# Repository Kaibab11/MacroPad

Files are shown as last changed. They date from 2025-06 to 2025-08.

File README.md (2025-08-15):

# MacroPad

A customizable macro pad project featuring hardware design files, firmware, and a GUI for configuration.

## Features

- Custom PCB design files for a macro pad
- CircuitPython-based firmware for key handling and display
- Modular codebase for easy extension
- GUI software for configuration (see [Software/GUI](Software/GUI))
- Assembly and fabrication documentation

## Directory Structure

- **Firmware/**: CircuitPython firmware, including main logic (`main.py`), macro handling (`macroPad.py`), display support (`display/display.py`), and KMK keyboard modules.
- **PCB_FIles/**: Hardware design files, including schematic, PCB layout, and fabrication reports.
- **Software/GUI/**: GUI tools for configuring the macro pad.
- **Assembly/**, **Fabrication/**, **Schematic Prints/**: Documentation for building and assembling the macro pad.

## Getting Started

1. **Hardware**: Review PCB and schematic files in [PCB_FIles](PCB_FIles).
2. **Firmware**: Flash CircuitPython and copy files from [Firmware](Firmware) to your device.
3. **Configuration**: Use the GUI in [Software/GUI](Software/GUI) to set up macros.

## Requirements

- CircuitPython-compatible microcontroller
- KMK firmware (included in [Firmware/kmk](Firmware/kmk))
- Python 3.x for GUI tools

## License

This project is for personal and educational use.

---

For more details, see individual folders and documentation.

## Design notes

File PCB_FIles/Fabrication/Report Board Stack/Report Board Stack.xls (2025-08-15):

Board Stack Report
Stack Up |  | Layer Stack
Layer | Rigid | Name | Material | Thickness | Constant
1 |  | Top Overlay |  | 0mm
2 |  | Top Solder | Solder Resist | 0.0127mm | 3.3
3 |  | Top Layer |  | 0.01778mm
4 |  | Dielectric1 | FR-4 | 1.4986mm | 4.3
5 |  | Bottom Layer |  | 0.01778mm
6 |  | Bottom Solder | Solder Resist | 0.0127mm | 3.3
7 |  | Bottom Overlay |  | 0mm
 | Height : 1.55956mm

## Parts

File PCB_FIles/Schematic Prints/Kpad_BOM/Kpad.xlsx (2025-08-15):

Designator | Description | Name | Quantity | Manufacturer 1 | Manufacturer Part Number 1 | Supplier 1 | Supplier Part Number 1
MT1 | Incremental Encoder, 12 Mm, Contact Rating 10 Ma - 5 Vdc | PEC11R-4215F-S0024 | 1 | Bourns | PEC11R-4215F-S0024 | Arrow Electronics | PEC11R-4215F-S0024
R1, R2, R3 | Axial Resistor, 10 KOhm, +/- 1%, 0.25 W, -55 to 155 degC, 2-Pin THD, RoHS, Bulk | MFR-25FBF52-10K | 3 | Yageo | MFR-25FBF52-10K | Avnet | MFR-25FBF52-10K
SW1, SW2, SW3, SW4, SW5, SW6, SW7, SW8, SW9, SW10, SW11, SW12 | SPST momentary switch 15.40mmx15.40mm | KS-8A10B055NW | 12 | Gateron | KS-8A10B055NW-D194 | Divinikey | DK002607
U1, U3 | Parallel-Load Shift Register, 8-Bit, 2 to 6 V, -40 to 125 degC, 16-Pin PDIP (N), Pb-Free (RoHS), Rail/Tube | SN74HC165N | 2 | Texas Instruments | SN74HC165N | Digikey | 296-8251-5-ND
U2 | RP2040 XIAO RP2040 series ARMÂ® CortexÂ®-M0+ MCU 32-Bit Embedded Evaluation Board | 102010428 | 1 | Seeed Technology Co., Ltd | 102010428 | Digikey | 1597-102010428-ND
U4 | MakerFocus 2pcs I2C OLED Display Module 0.91 Inch | 8541549353 | 1 | Shenzhen Jin Ma Ding Electronics Co., Ltd. | QG-2832TLBFG02 | MakerFocus | 8541549353
U5, U6 | RES ARRAY 7 RES 1K OHM 14DIP | 4114R-1-102LF | 2 | Bourns | 4114R-1-102LF | Newark | 32K8310

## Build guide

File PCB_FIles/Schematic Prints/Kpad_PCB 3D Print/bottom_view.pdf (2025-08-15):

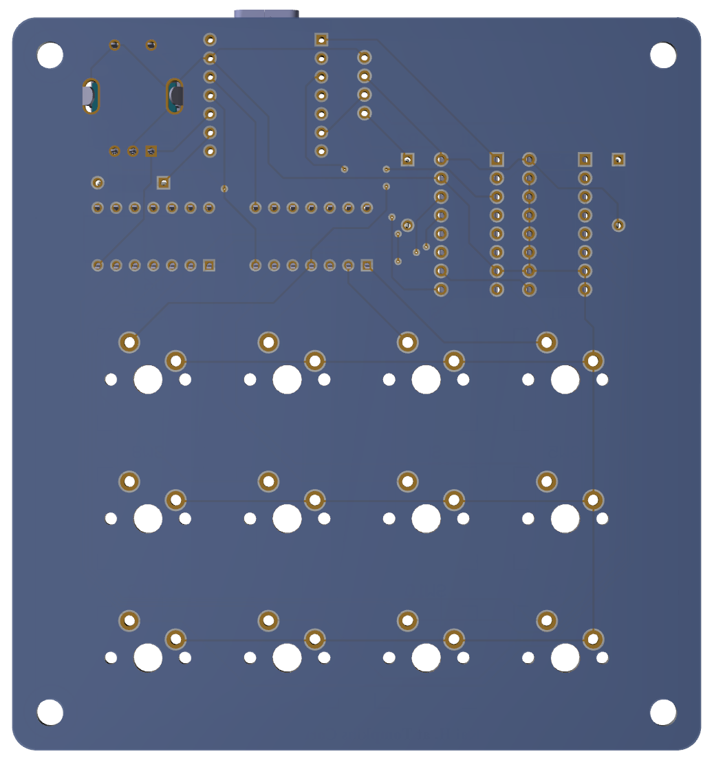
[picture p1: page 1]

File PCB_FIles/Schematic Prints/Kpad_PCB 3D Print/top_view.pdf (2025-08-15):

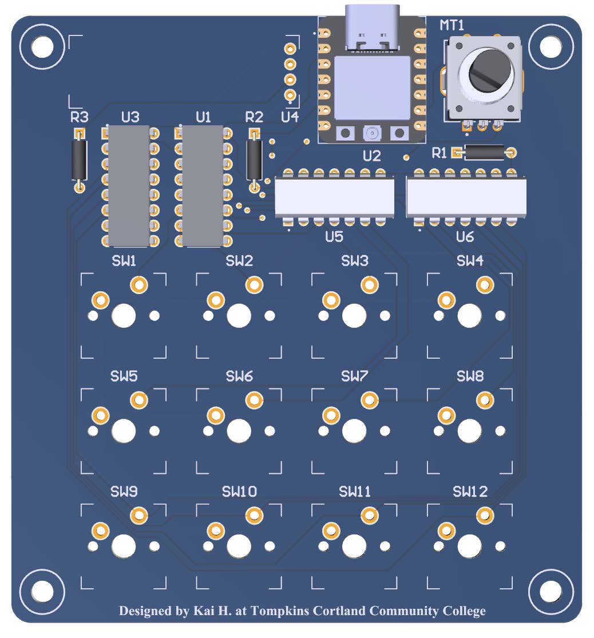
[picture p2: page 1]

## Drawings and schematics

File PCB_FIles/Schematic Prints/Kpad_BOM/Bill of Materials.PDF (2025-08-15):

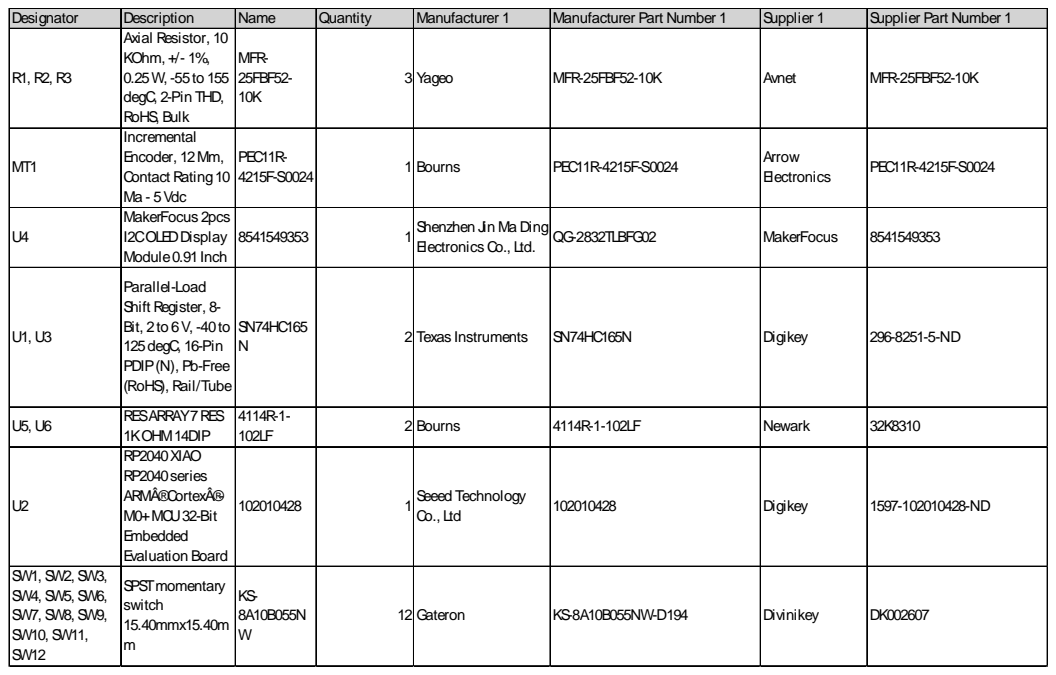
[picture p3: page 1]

Designator | Description | Name | Quantity | Manufacturer 1 | Manufacturer Part Number 1 | Supplier 1 | Supplier Part Number 1
R1, R2, R3 | Axial Resistor, 10 KOhm, +/- 1%, 0.25W, -55to 155 degC, 2-Pin THD, RoHS, Bulk | MFR-25FBF52-10K | 3 Yageo | | MFR-25FBF52-10K | Avnet | MFR-25FBF52-10K

MT1 | Incremental Encoder, 12Mm, Contact Rating10 Ma - 5Vdc | PEC11R-4215F-S0024 | 1 Bourns | | PEC11R-4215F-S0024 | Arrow Electronics | PEC11R-4215F-S0024

U4 | MakerFocus 2pcs I2COLEDDisplay Module0.91Inch | 8541549353 | 1 Shenzhen Jin Ma Ding | Electronics Co., Ltd. | QG-2832TLBFG02 | MakerFocus | 8541549353

U1, U3 | Parallel-Load Shift Register, 8-Bit, 2to 6V, -40to 125degC, 16-Pin PDIP(N), Pb-Free (RoHS), Rail/Tube | SN74HC165 N | 2 Texas Instruments | | SN74HC165N | Digikey | 296-8251-5-ND

U5, U6 | RESARRAY7RES 1KOHM14DIP | 4114R-1-102LF | 2 Bourns | | 4114R-1-102LF | Newark | 32K8310

U2 | RP2040XIAO RP2040series ARMÂ®CortexÂ®-M0+MCU32-Bit Embedded Evaluation Board | 102010428 | 1 Seeed Technology | Co., Ltd | 102010428 | Digikey | 1597-102010428-ND

SW1, SW2, SW3, SW4, SW5, SW6, SW7, SW8, SW9, SW10, SW11, SW12 | SPSTmomentary switch 15.40mmx15.40m m | KS-8A10B055N W | 12 Gateron | | KS-8A10B055NW-D194 | Divinikey | DK002607

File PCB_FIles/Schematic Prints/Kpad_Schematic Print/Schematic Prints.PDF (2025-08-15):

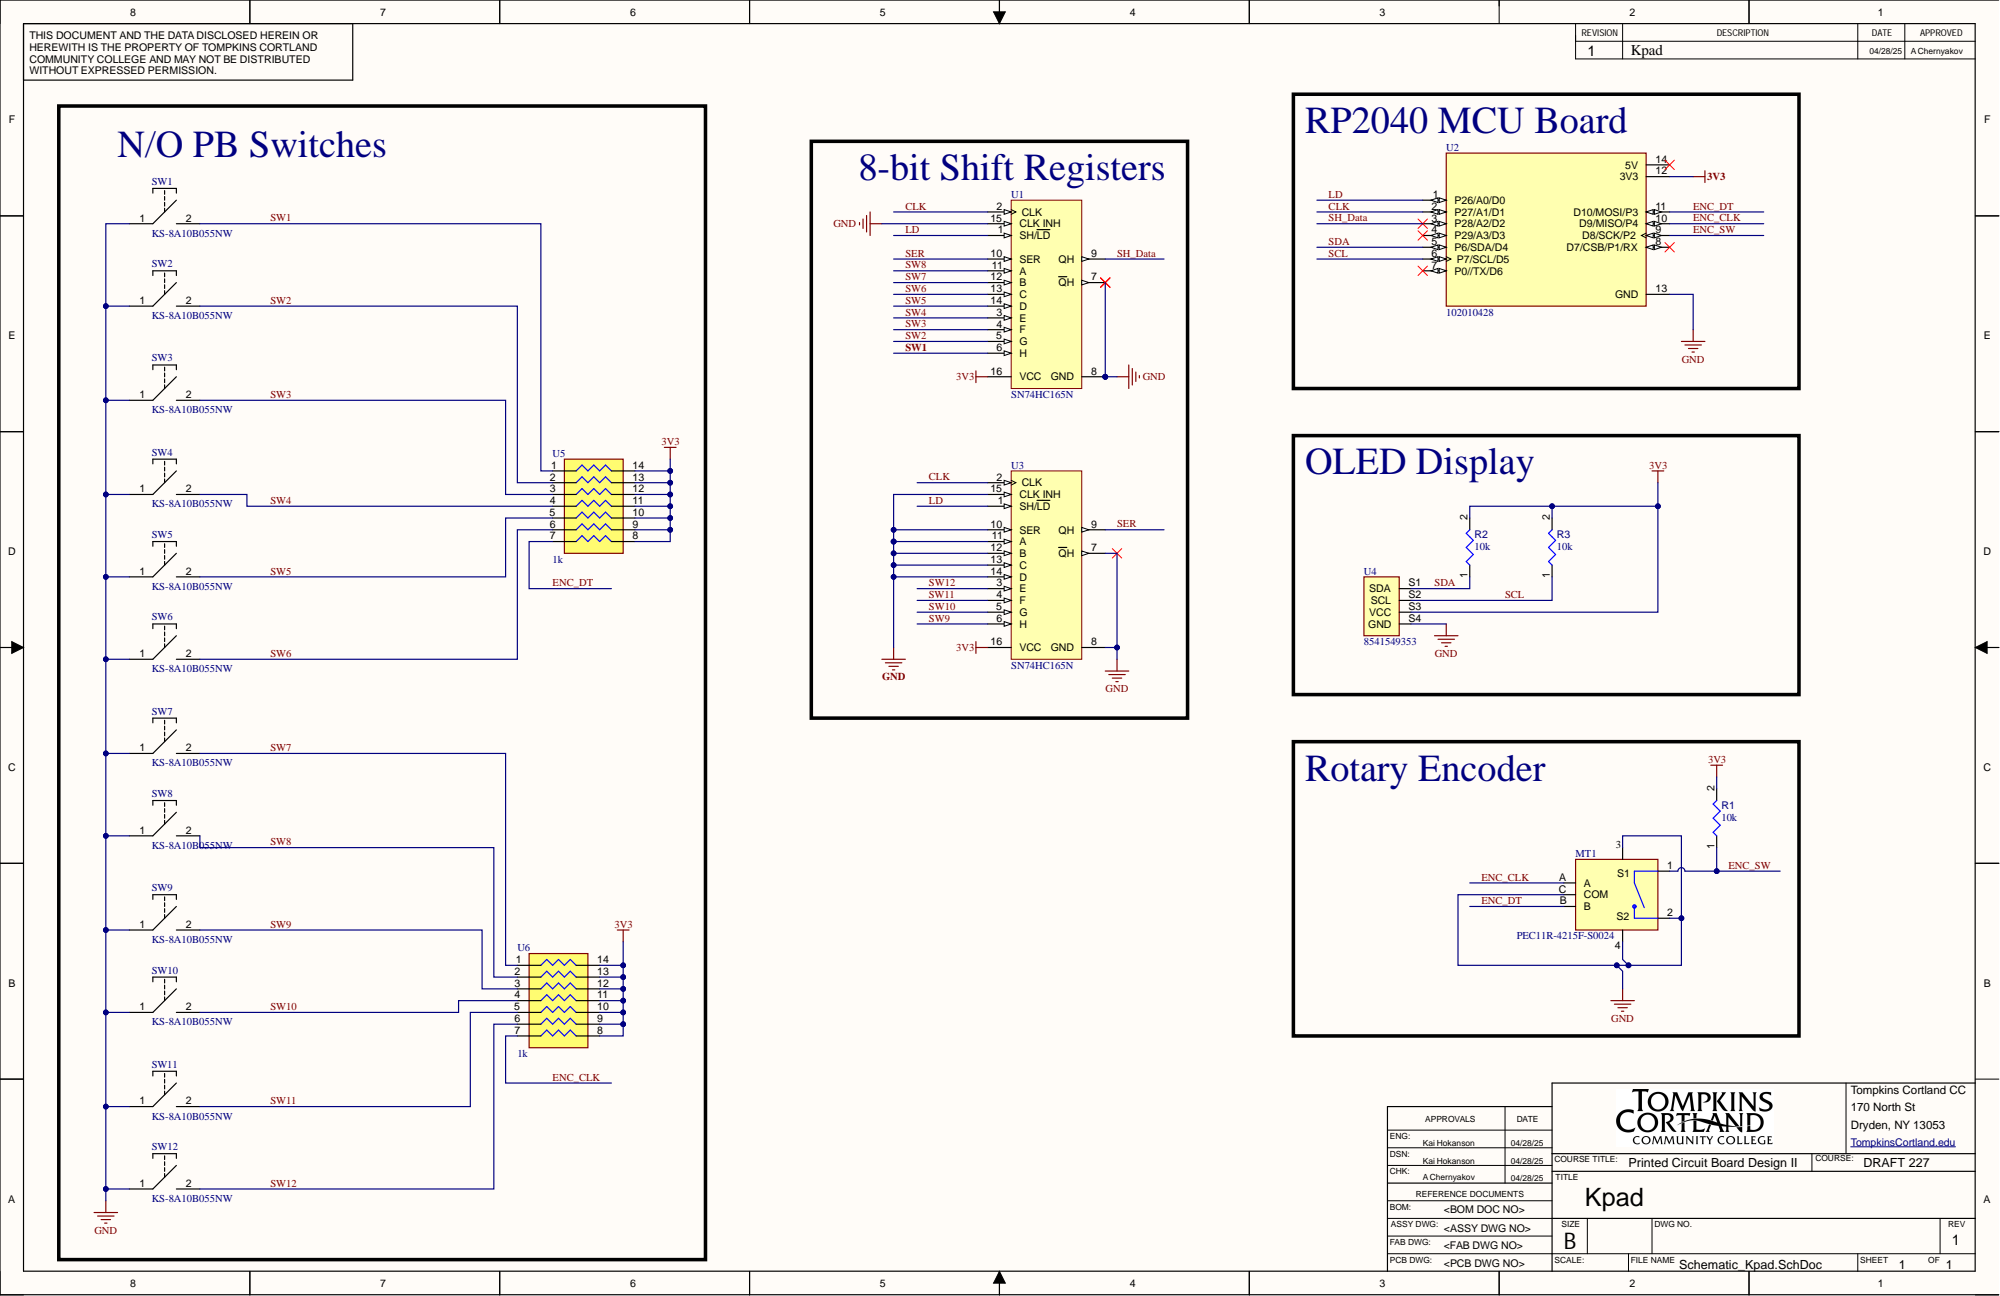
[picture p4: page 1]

HEREWITH IS THE PROPERTY OF
COMMUNITY COLLEGE AND MAY NOT BE DISTRIBUTED
WITHOUT EXPRESSED PERMISSION.
N/O PB Switches

Tompkins Cortland CC 170 North St TompkinsCortland. e d u

ENG : Kai Hokanson | 04/28/2 5

DSN: Kai Hokanson | 04/28/2 5

COURSE TITLE: Printed Circuit Board Design II | COURSE: DRAFT 227

CHK: A Chernyakov | 04/28/2 5

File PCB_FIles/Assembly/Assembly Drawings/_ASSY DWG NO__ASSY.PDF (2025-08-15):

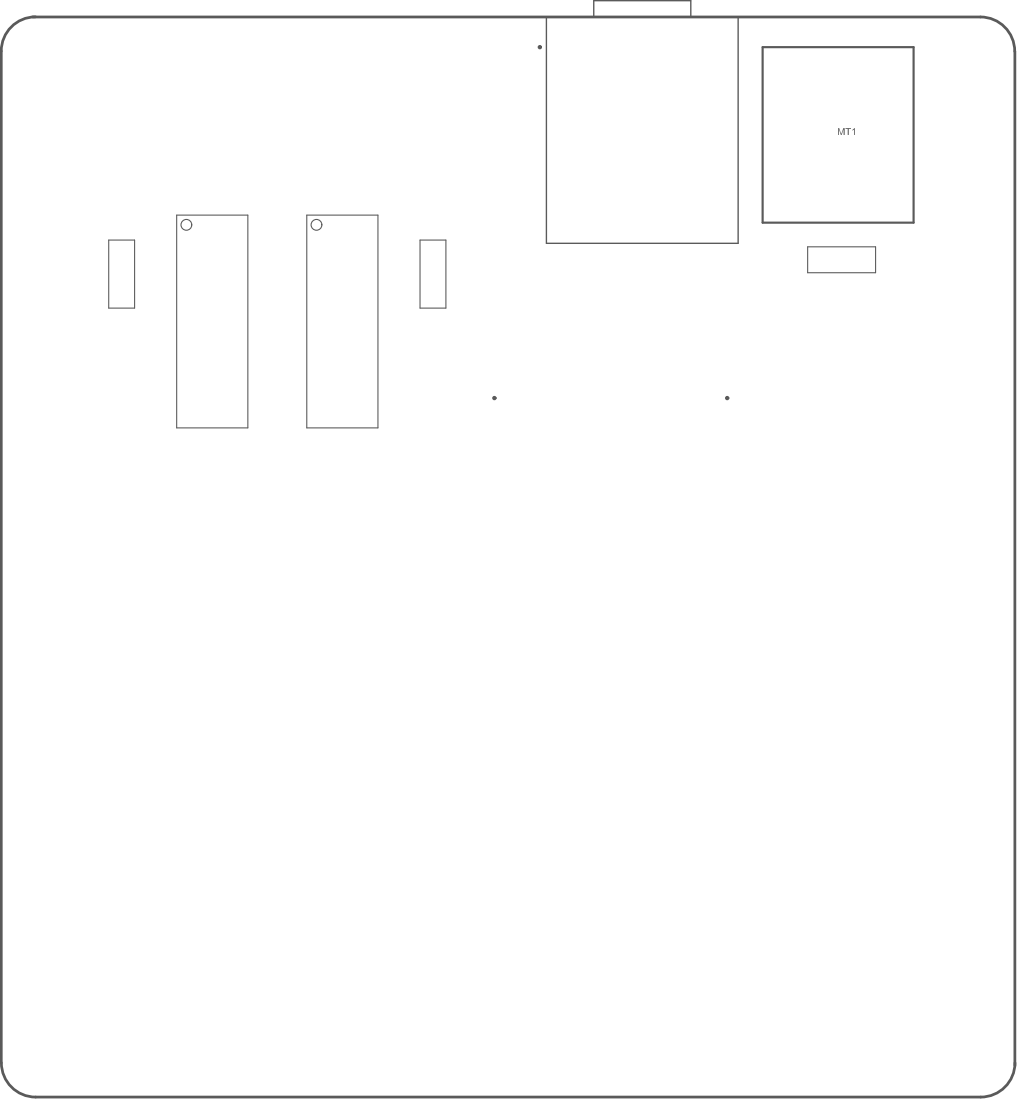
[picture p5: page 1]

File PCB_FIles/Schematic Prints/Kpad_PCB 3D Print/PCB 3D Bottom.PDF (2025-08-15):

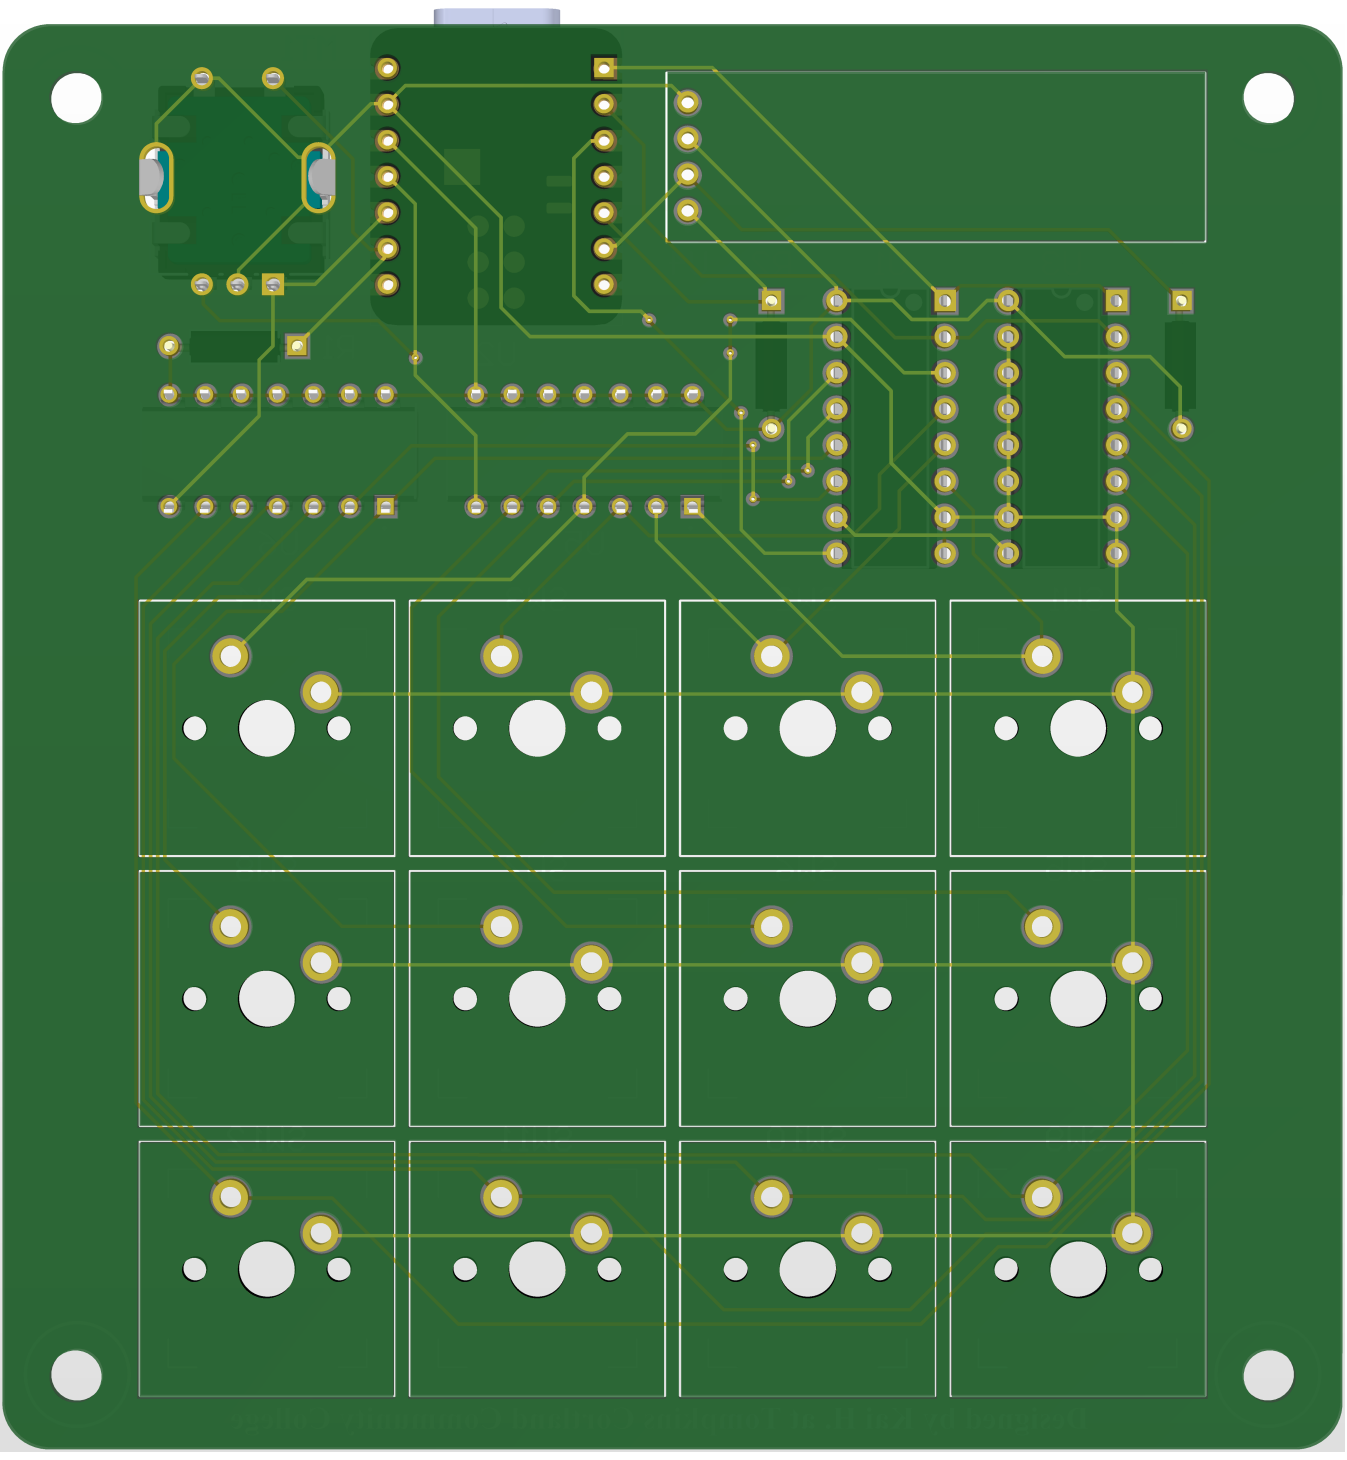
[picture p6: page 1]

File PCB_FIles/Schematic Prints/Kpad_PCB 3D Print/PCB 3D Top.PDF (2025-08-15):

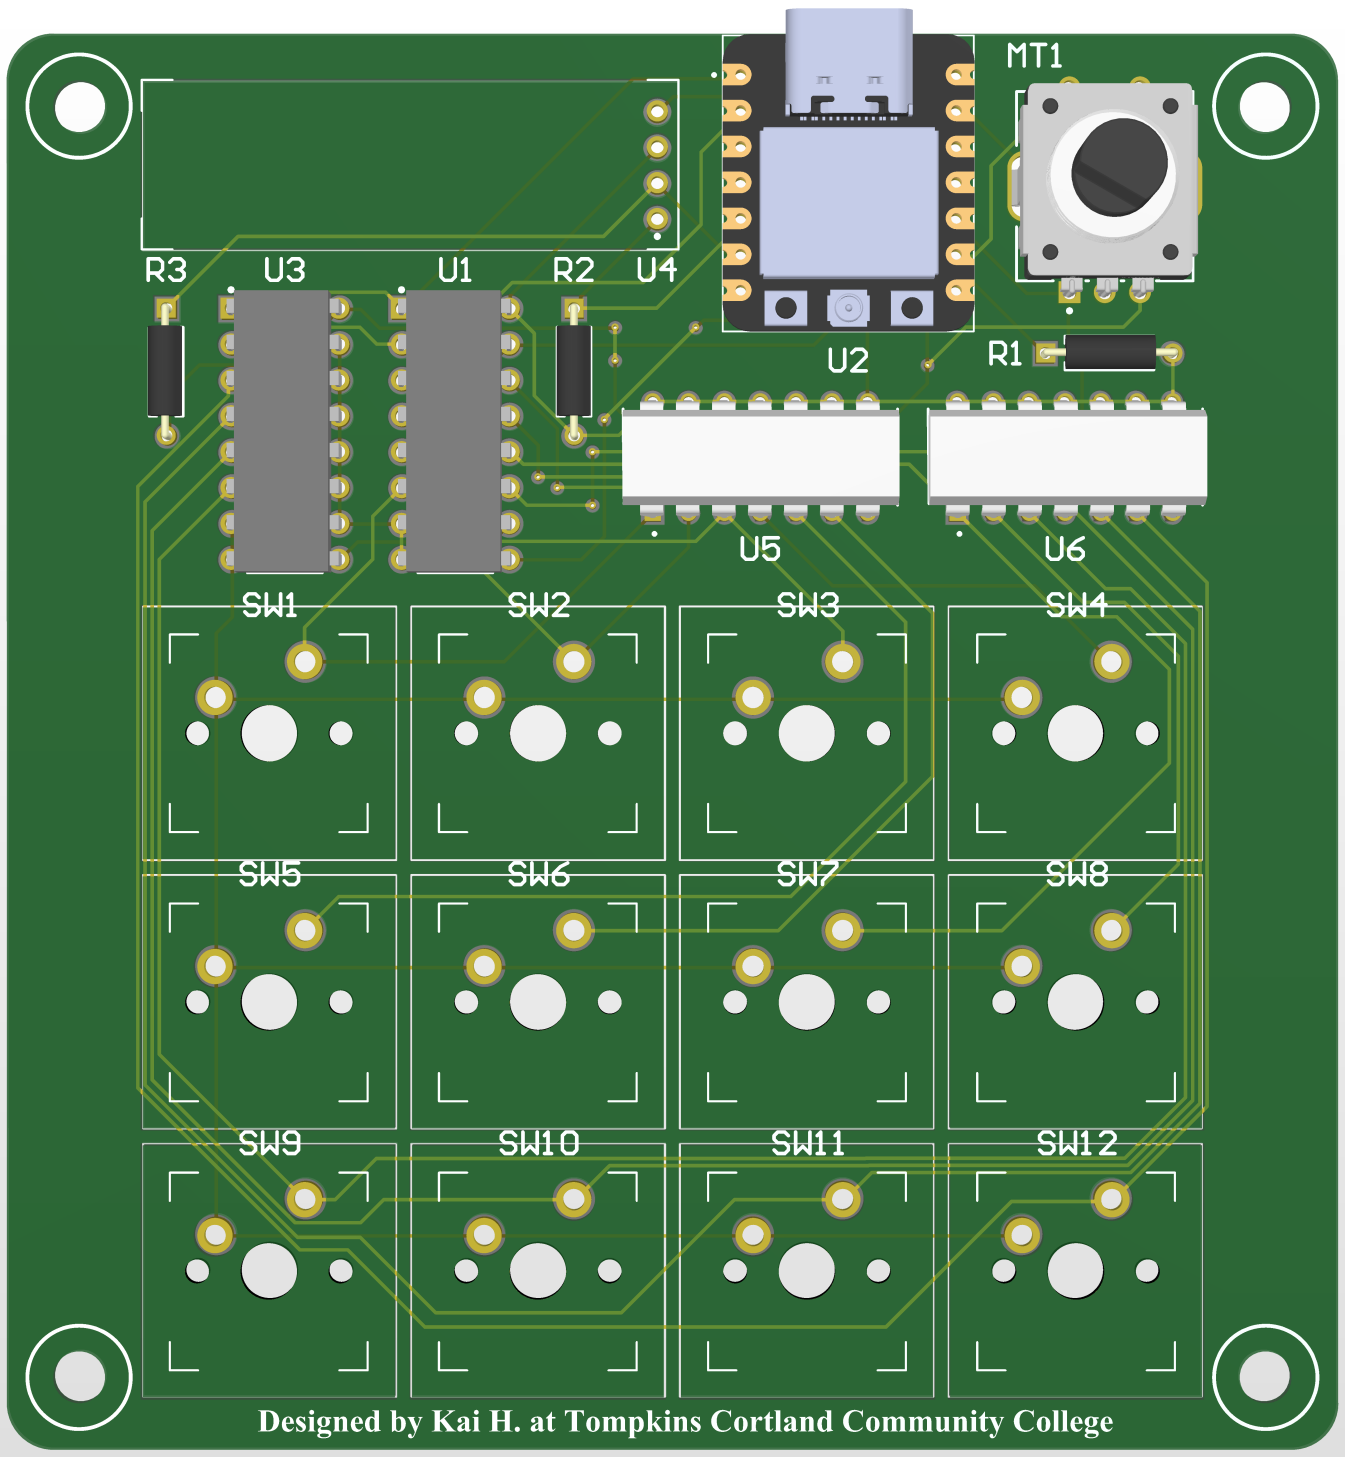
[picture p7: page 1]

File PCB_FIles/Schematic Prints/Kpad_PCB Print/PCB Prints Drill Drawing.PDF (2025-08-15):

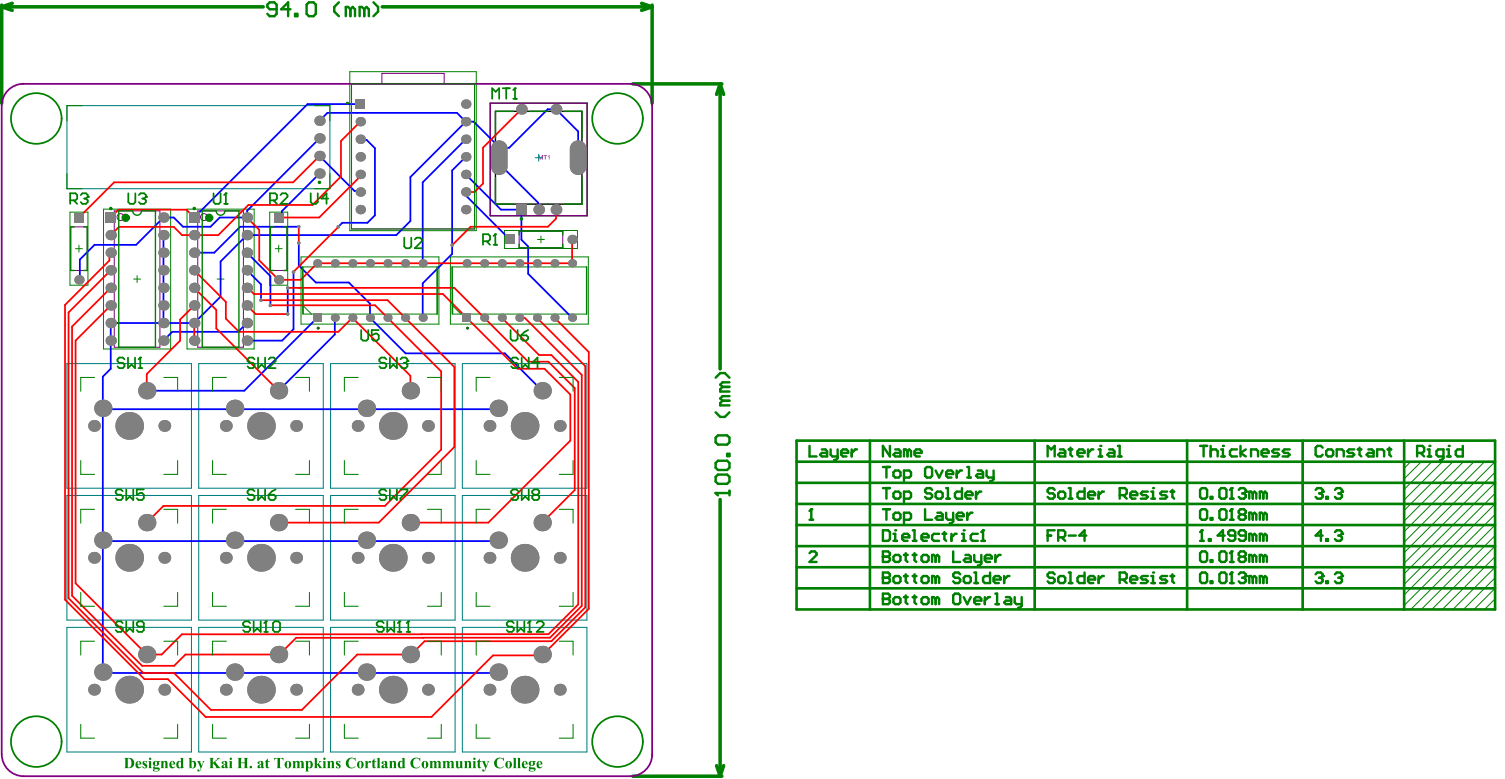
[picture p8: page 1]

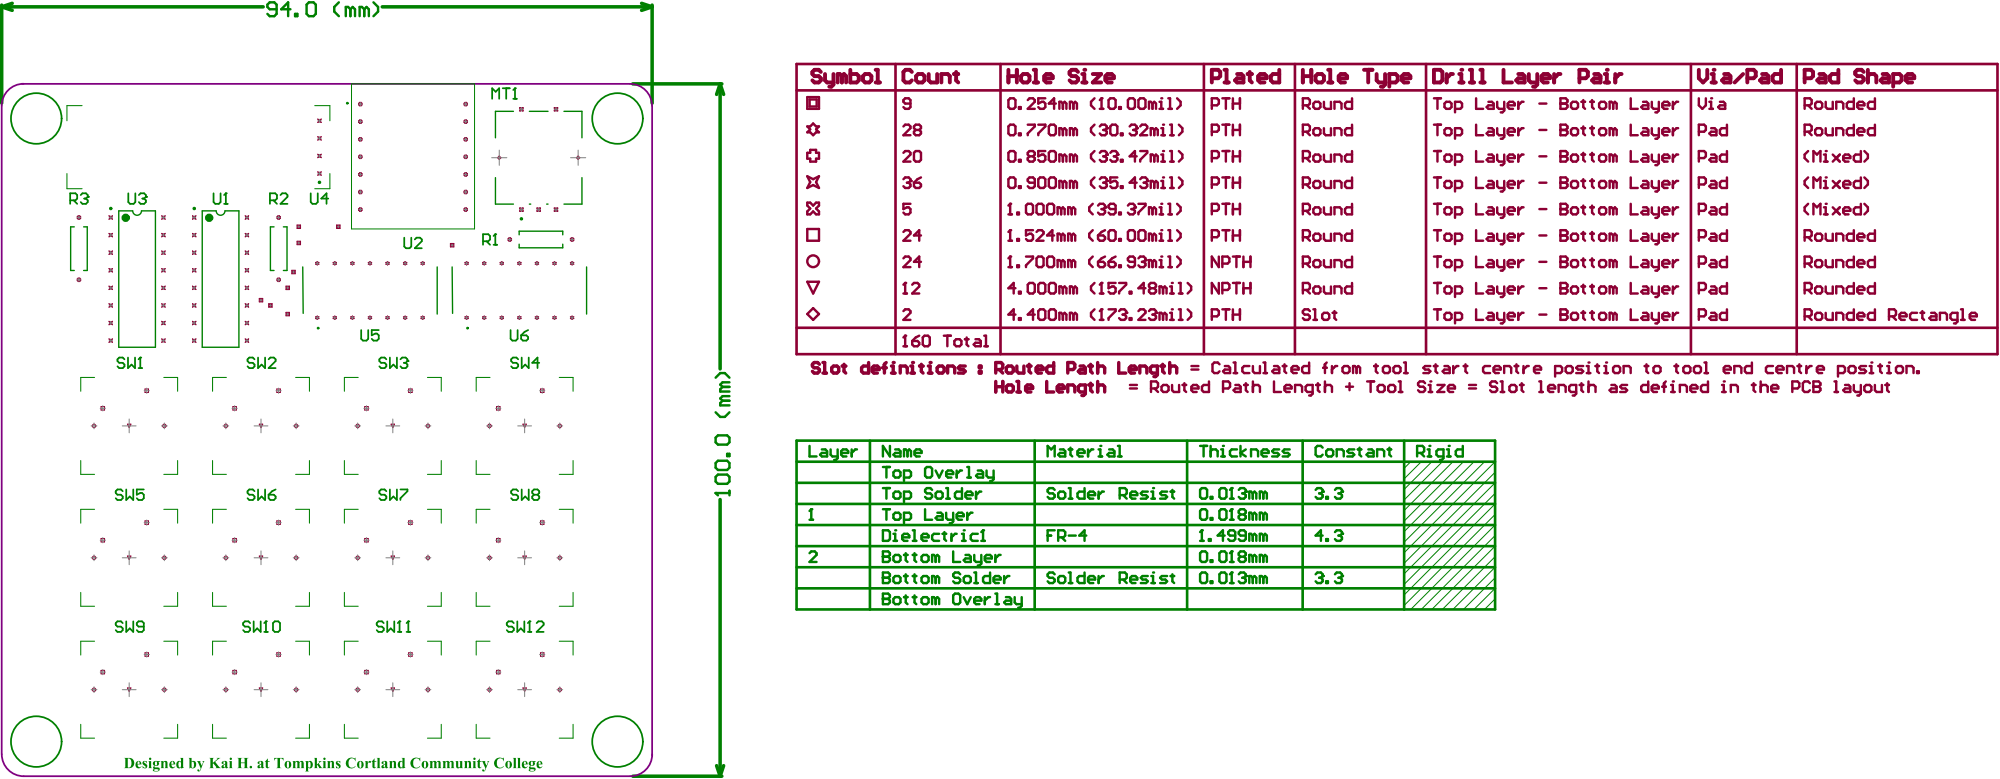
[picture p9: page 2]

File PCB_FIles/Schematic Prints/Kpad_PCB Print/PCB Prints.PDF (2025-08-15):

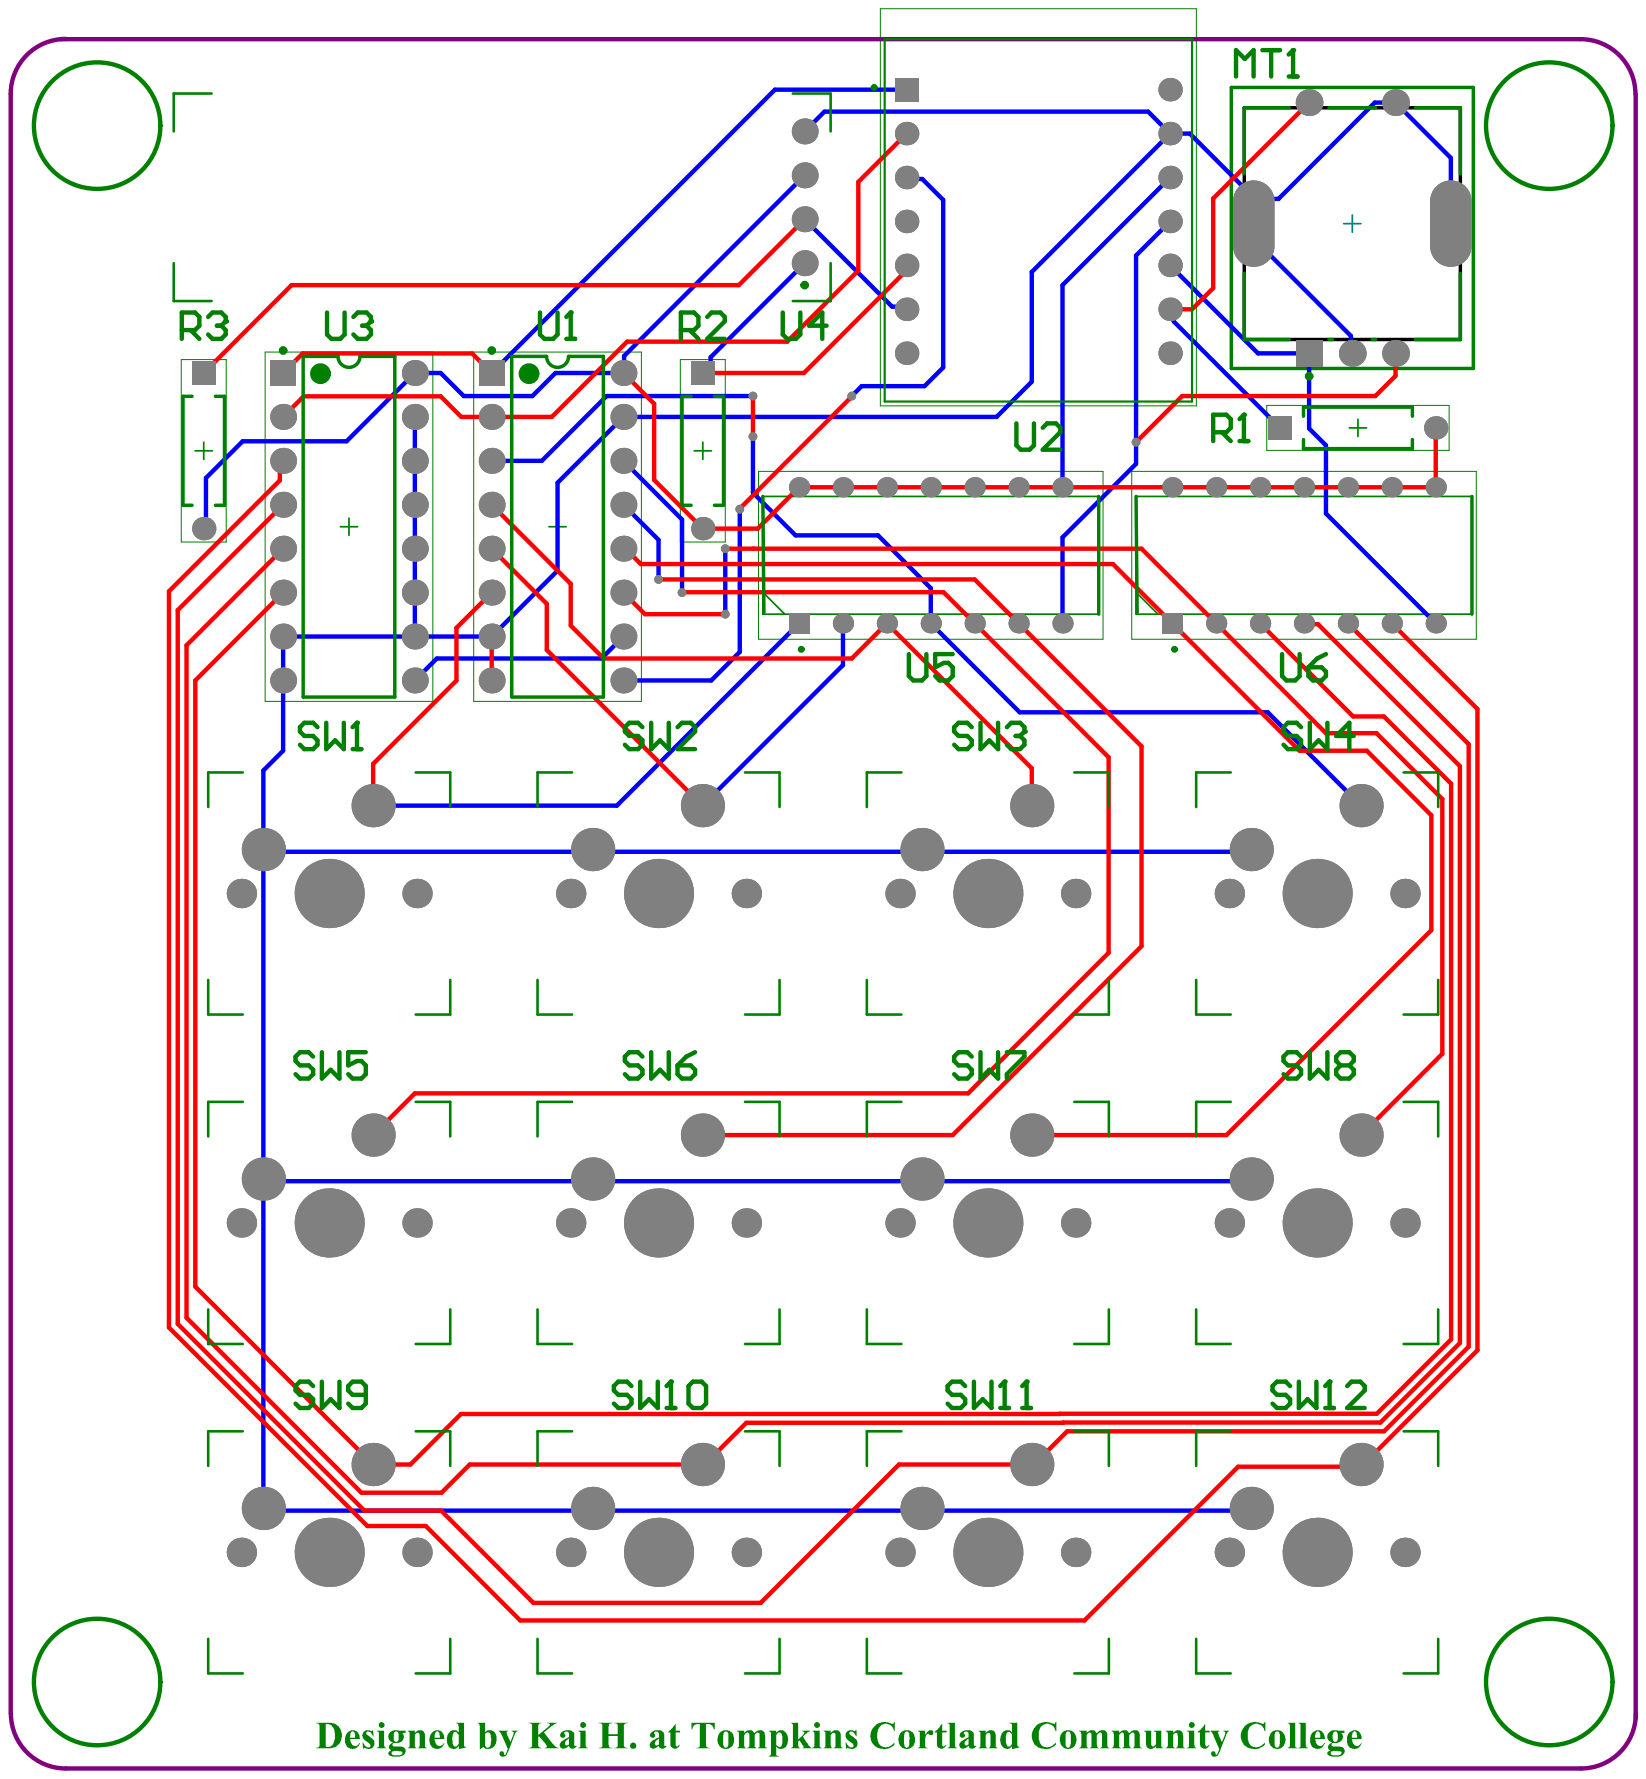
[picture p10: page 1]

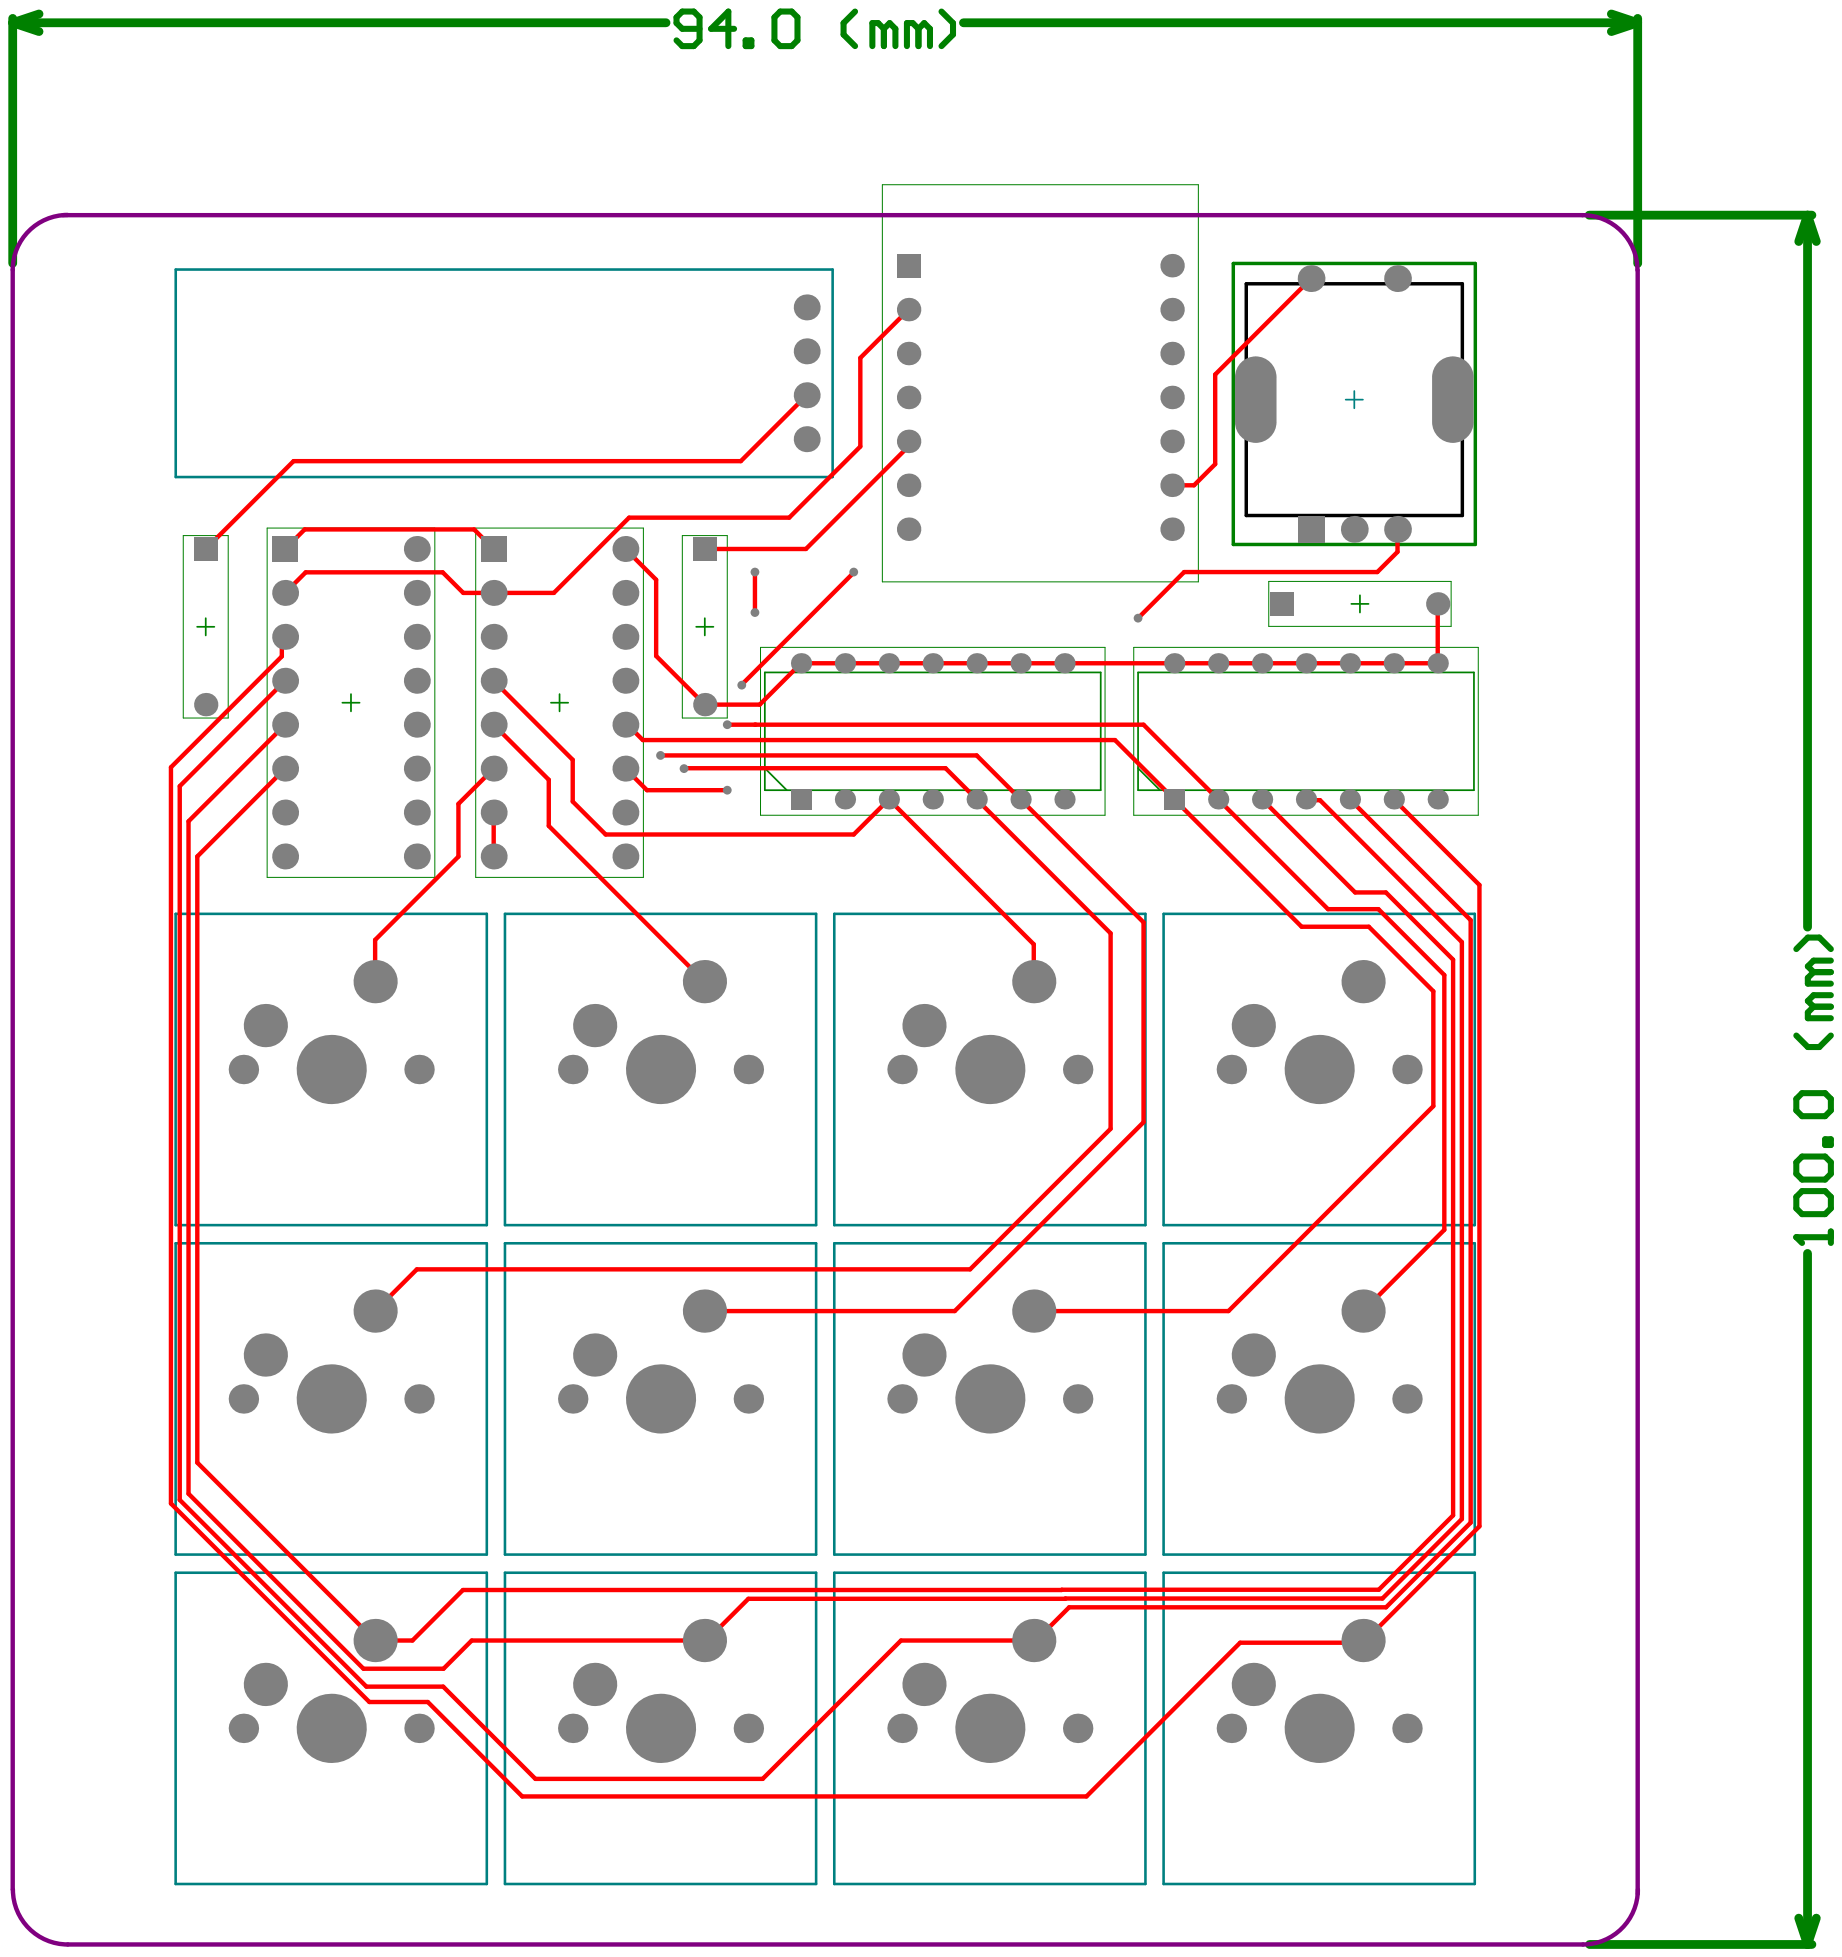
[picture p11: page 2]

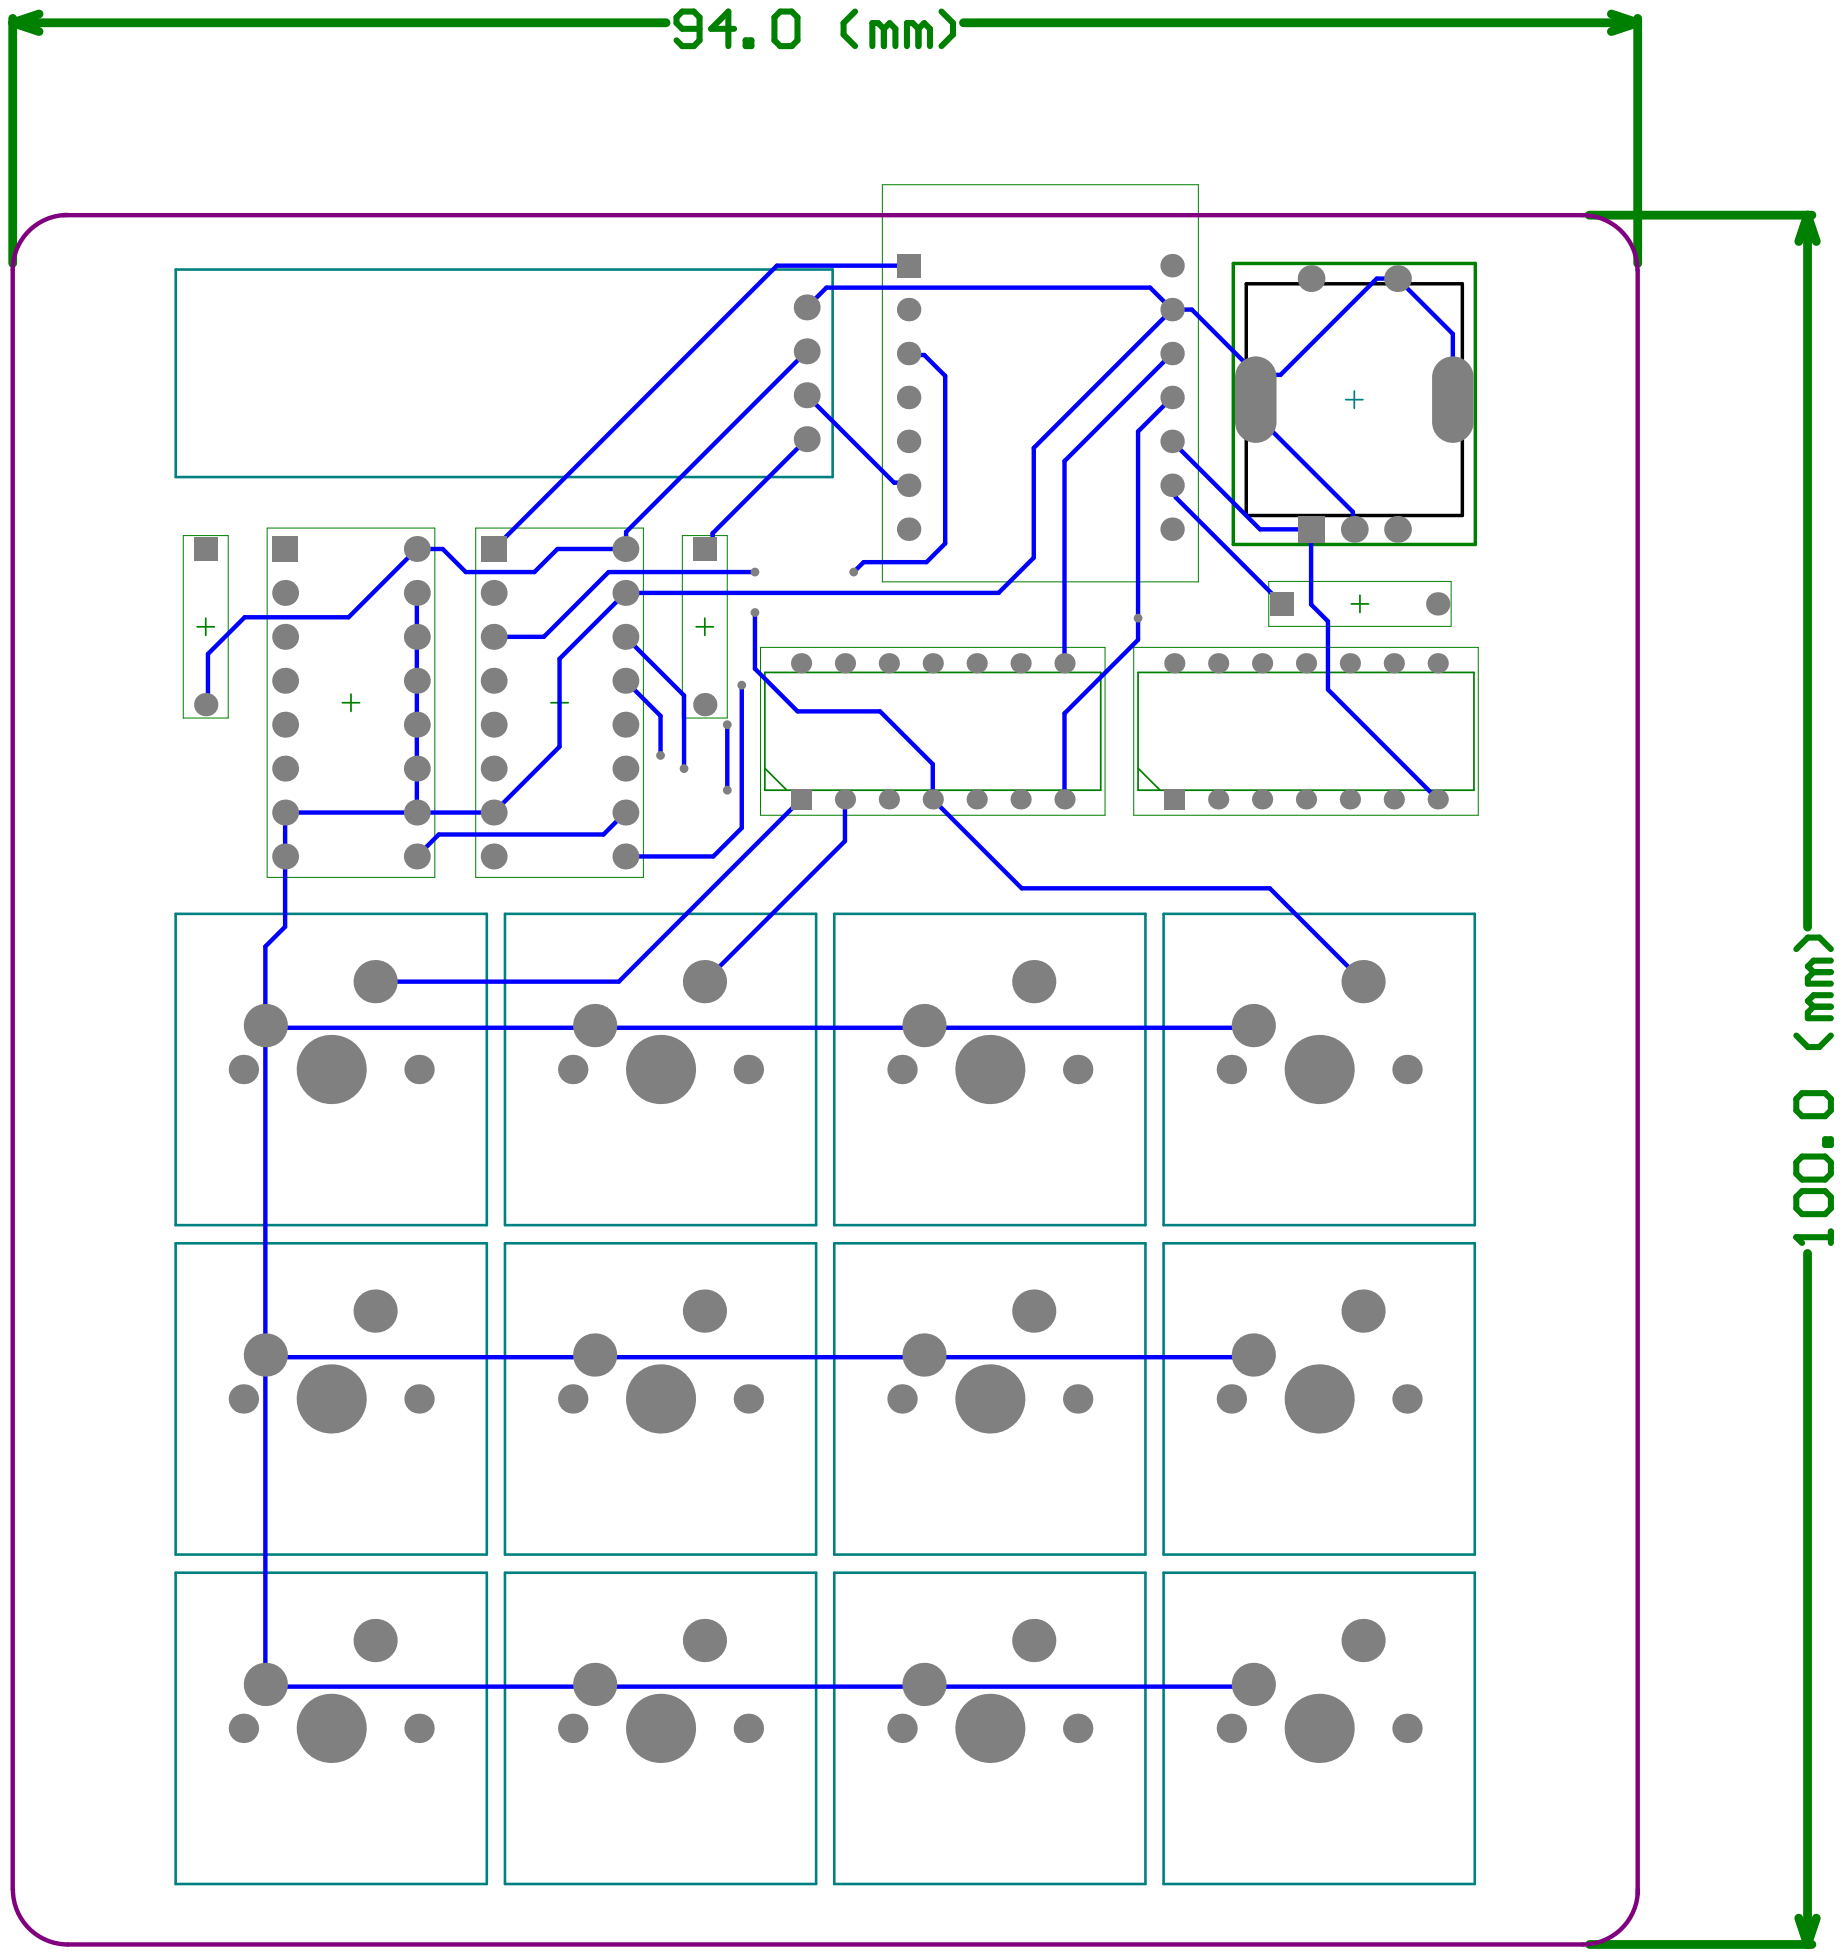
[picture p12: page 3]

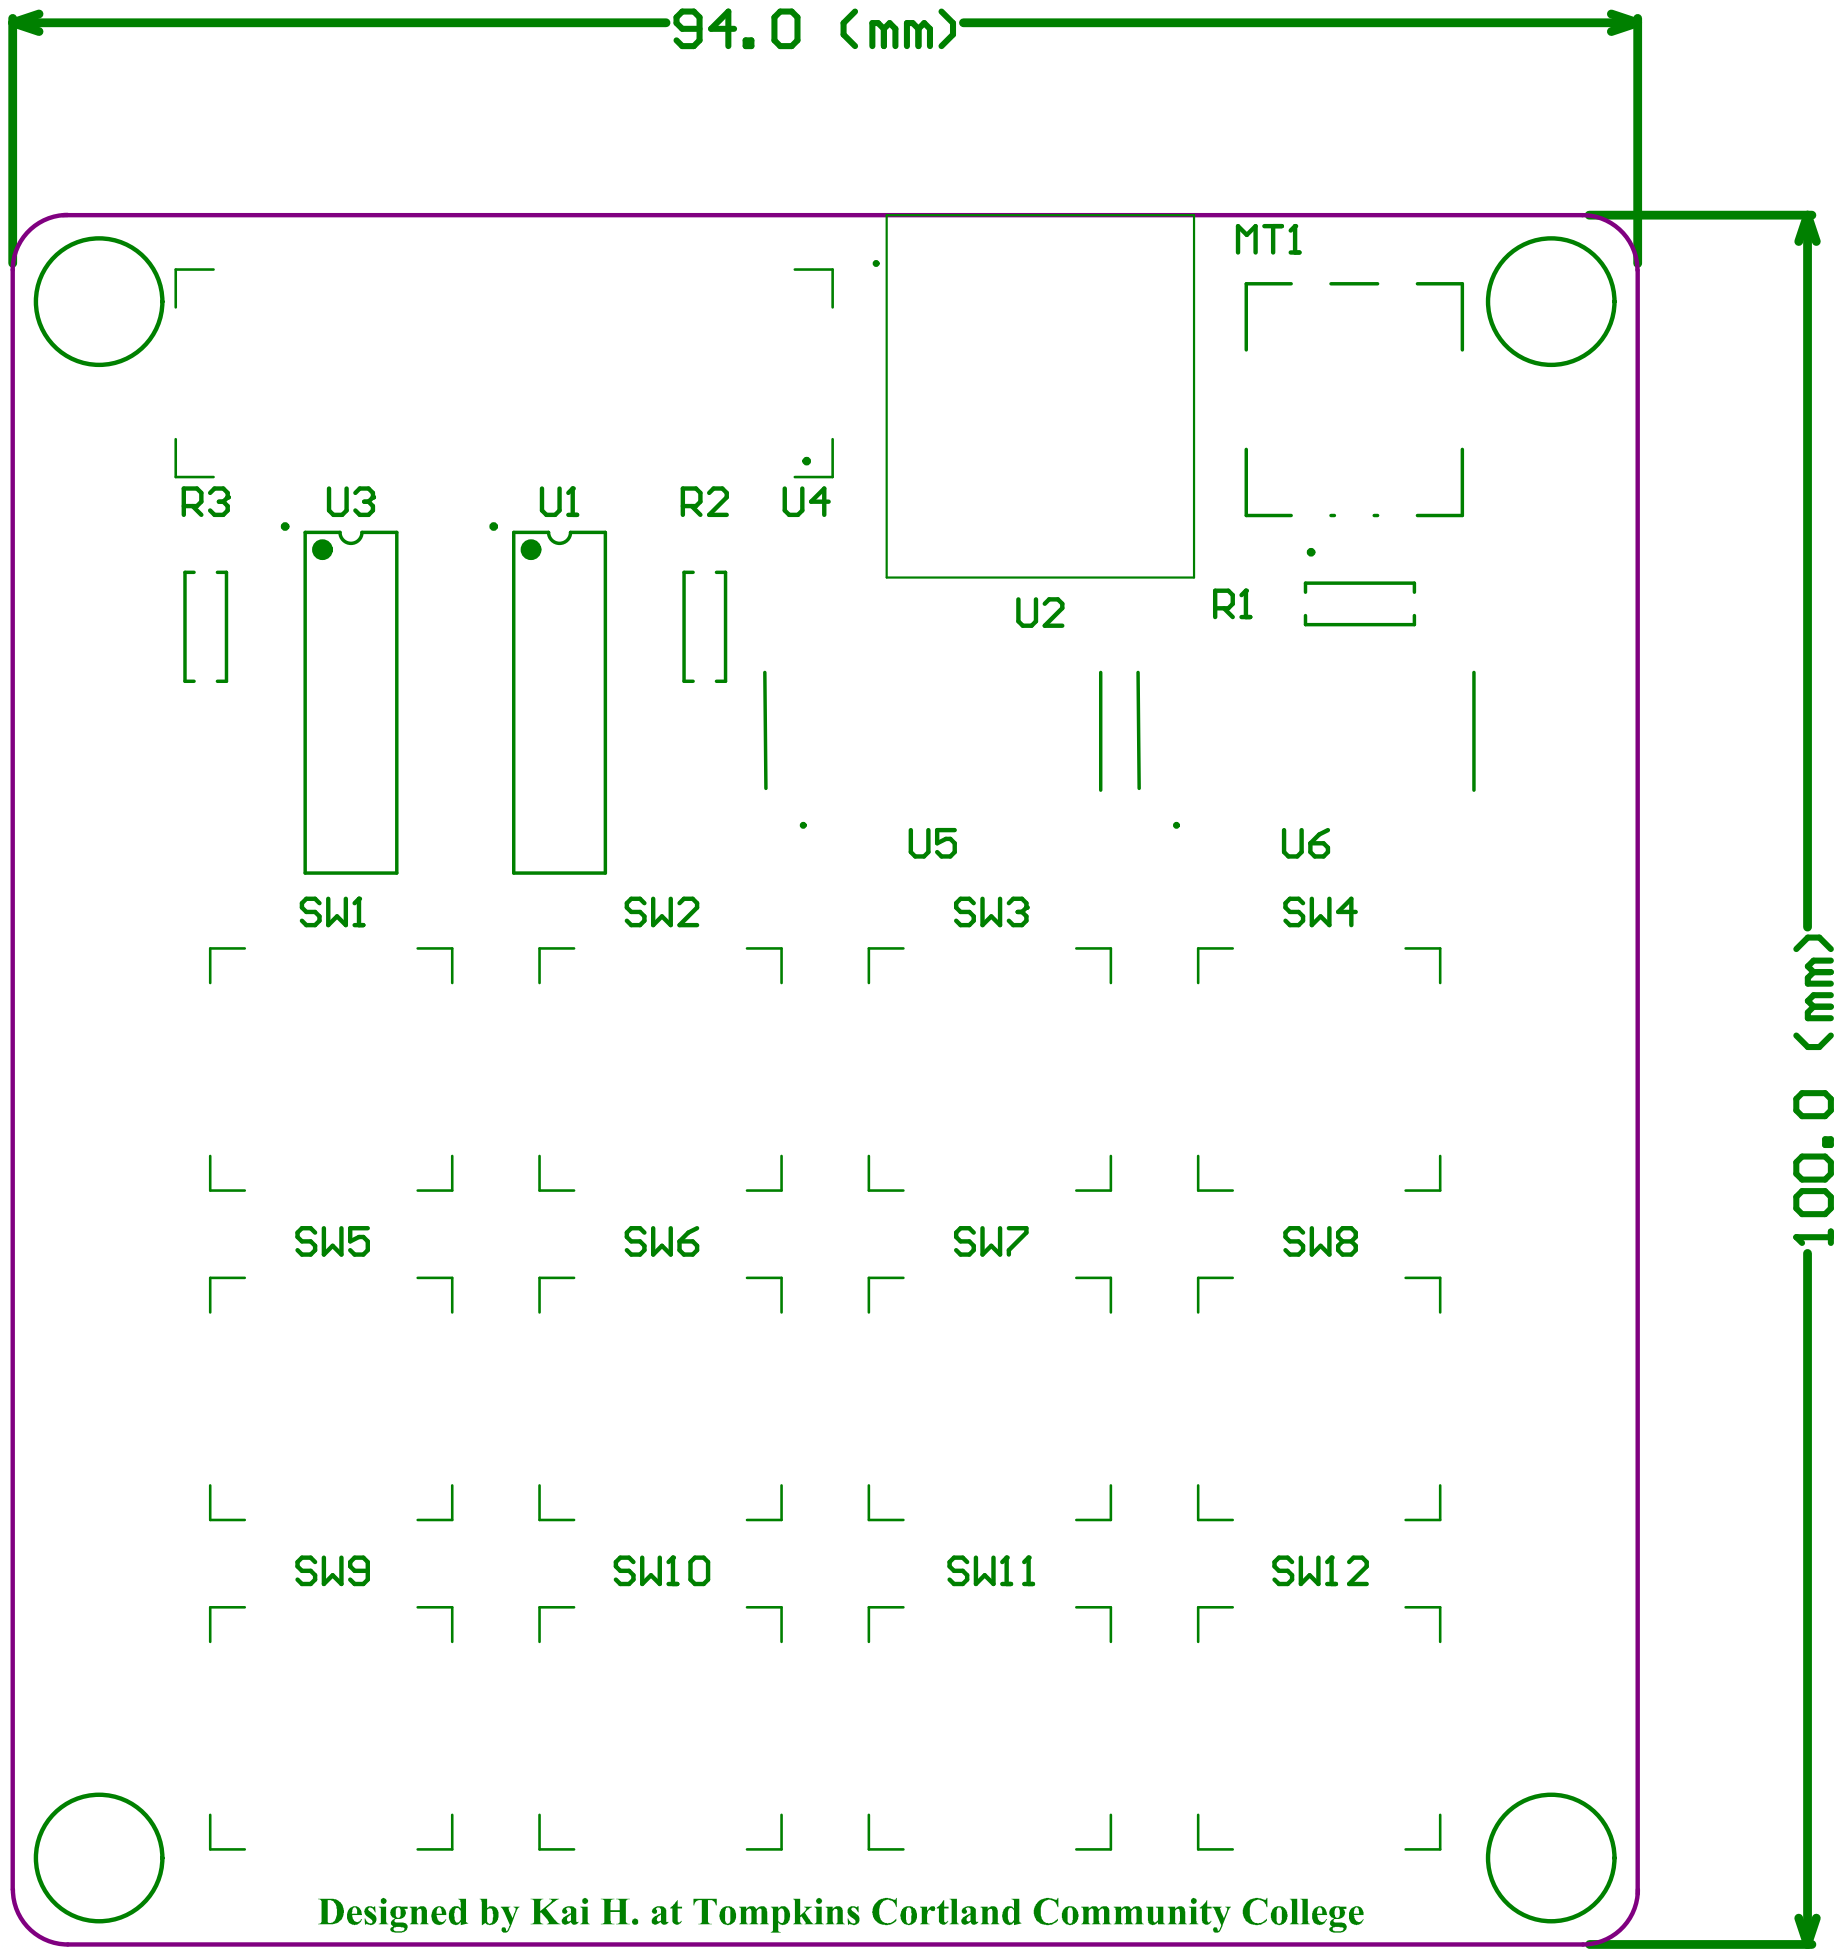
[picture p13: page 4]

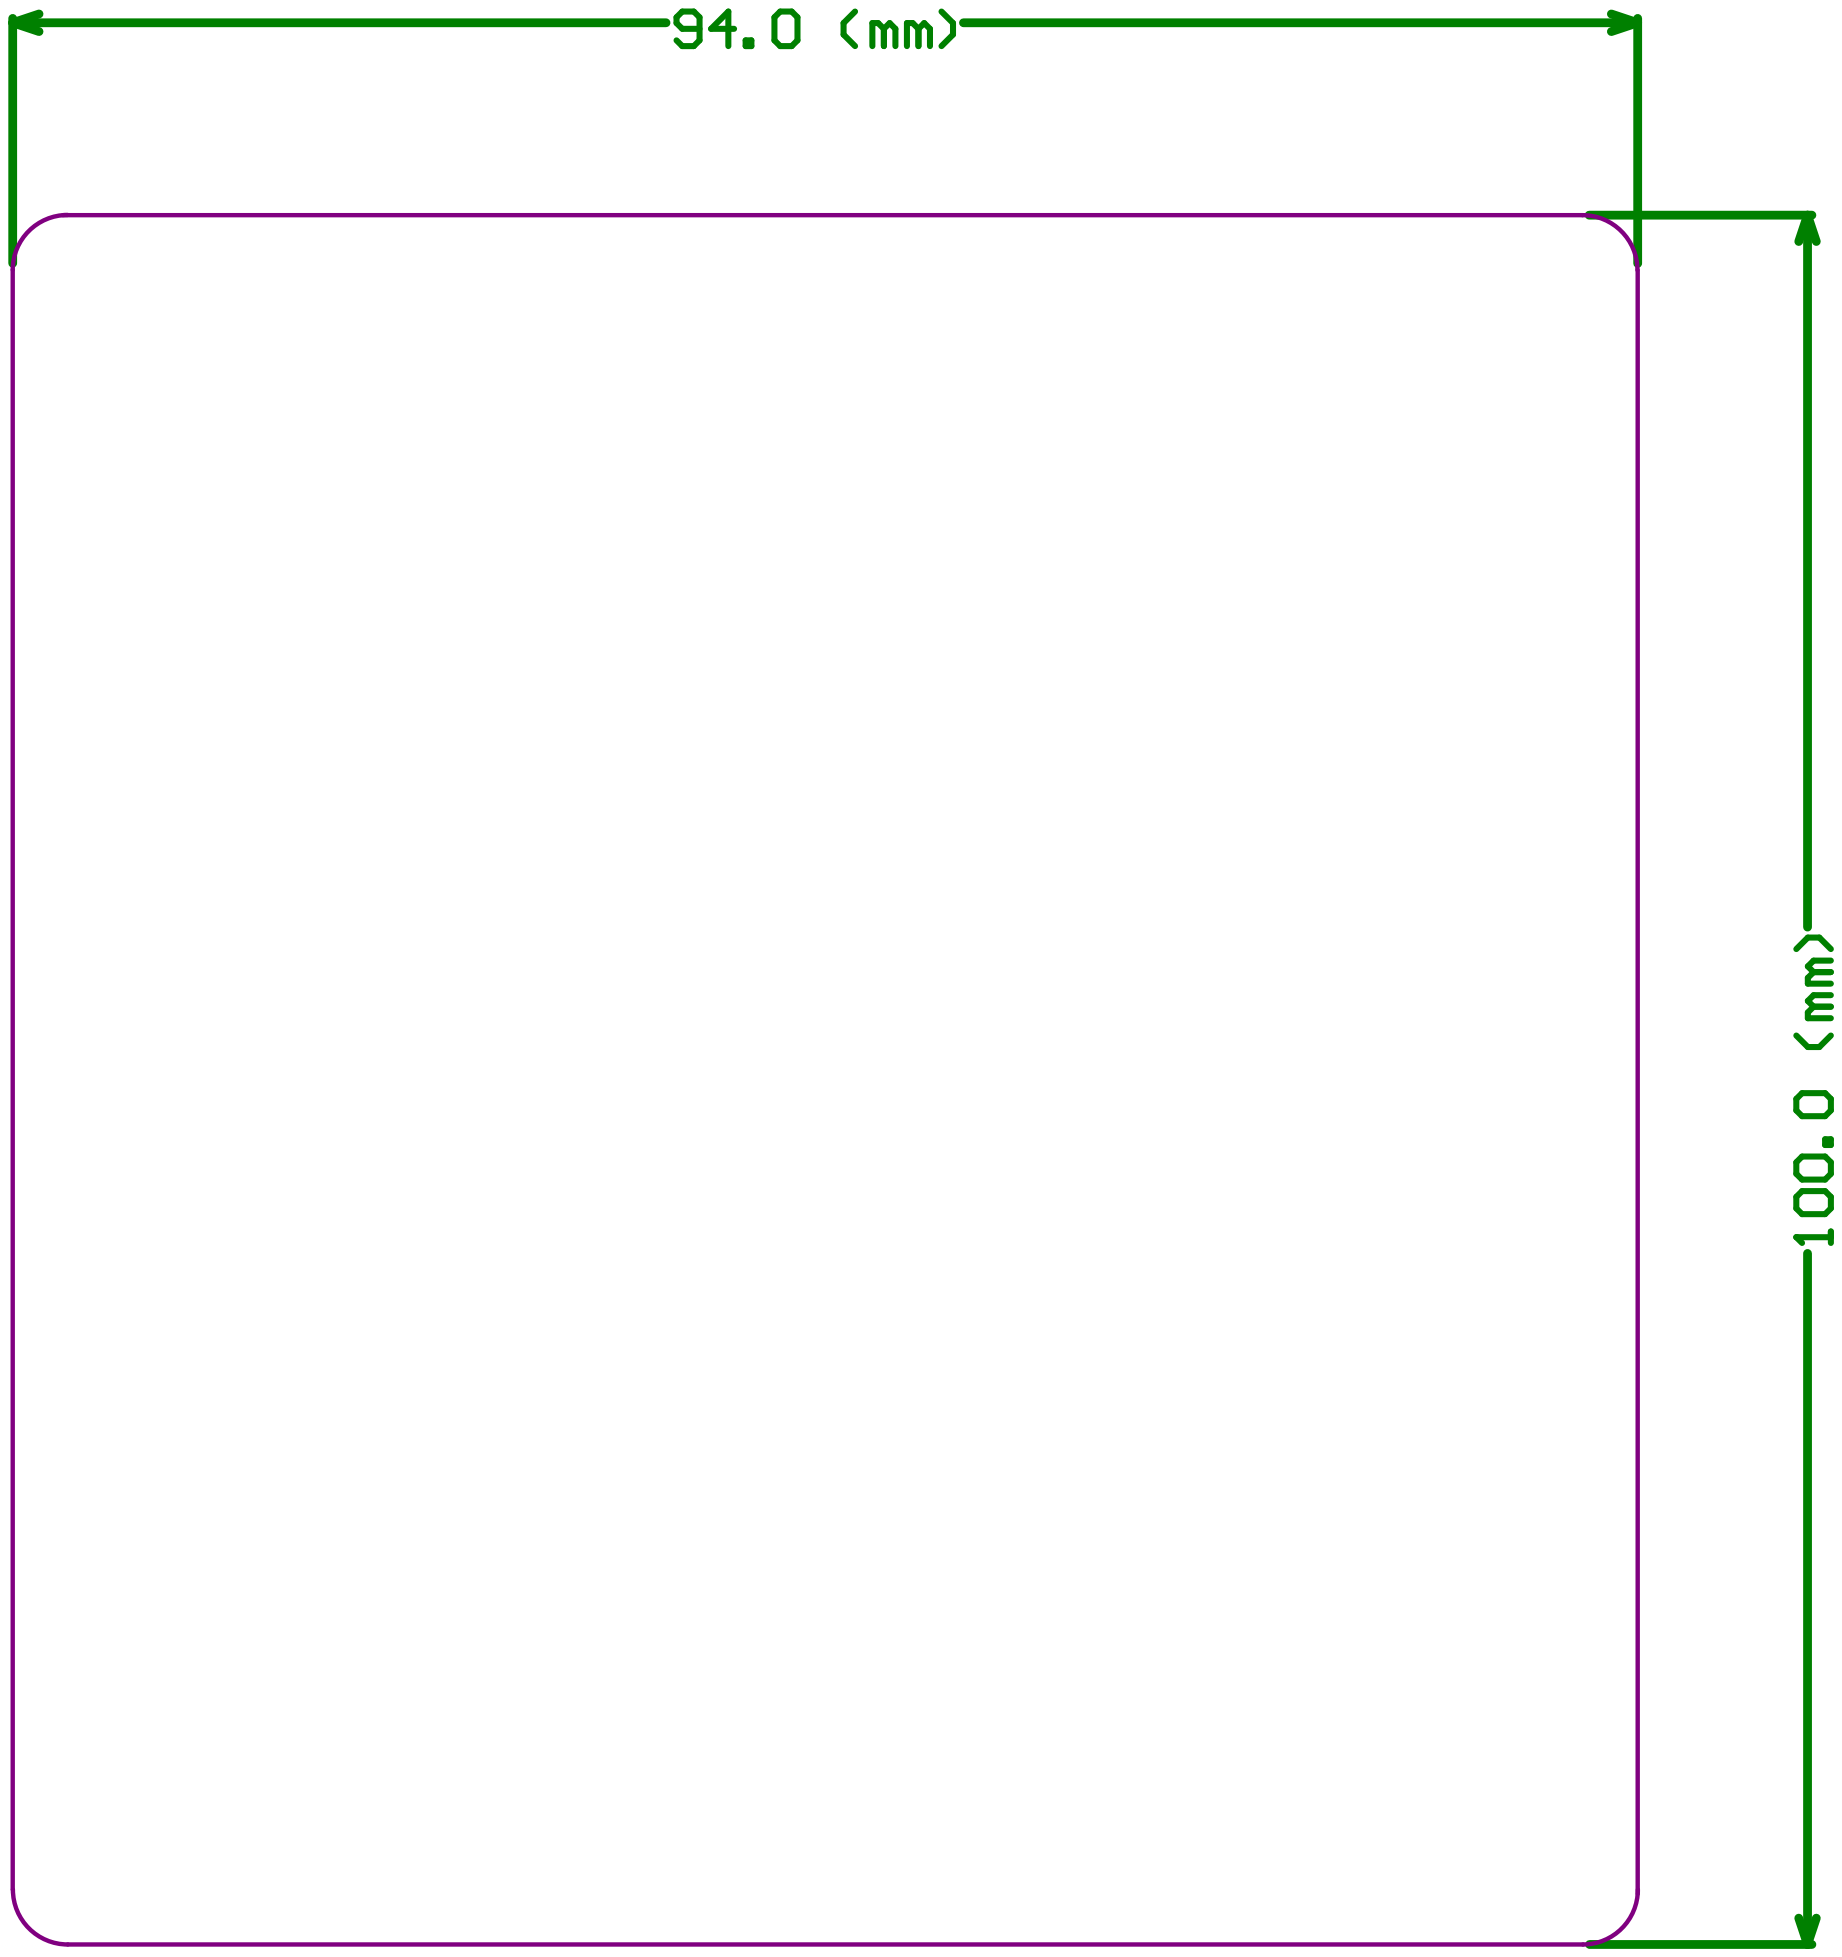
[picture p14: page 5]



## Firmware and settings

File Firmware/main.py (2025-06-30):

import json
import os
import supervisor
import time
from kmk.keys import KC
import board
import busio
import displayio
import sys

import time
from kmk.keys import Key
from macroPad import Kpad
from kmk.keys import KC
from kmk.modules.layers import Layers
from kmk.modules.encoder import EncoderHandler
from kmk.extensions.media_keys import MediaKeys
from kmk.modules.holdtap import HoldTap
from kmk.modules.macros import Macros
from display.display import DisplayScene
from kmk.modules import Module

# Custom Serial Communication Module
class SerialCommandModule(Module):
    def __init__(self):
        super().__init__()
        self.last_check = 0
        self.check_interval = 0.05  # Check every 50ms
        
    def during_bootup(self, keyboard):
        """Called during keyboard initialization"""
        self.keyboard = keyboard
        print("SerialCommandModule initialized")
        
    def before_matrix_scan(self, keyboard):
        """Called before each matrix scan - perfect for serial processing"""
        current_time = time.monotonic()
        if current_time - self.last_check > self.check_interval:
            self.process_serial_command()
            self.last_check = current_time

    def after_matrix_scan(self, keyboard):
        """Called after matrix scan - implement to avoid NotImplementedError"""
        pass
    
    def before_hid_send(self, keyboard):
        """Called before HID report is sent - implement to avoid NotImplementedError"""
        pass
    
    def after_hid_send(self, keyboard):
        """Called after HID report is sent - implement to avoid NotImplementedError"""
        pass
    
    def string_to_keycode(self, key_string):
        """Convert string like 'KC.A' to actual keycode"""
        key_string = key_string.strip()
        if key_string.startswith('KC.'):
            key_name = key_string[3:]
            try:
                keycode = getattr(KC, key_name)
                print(f"Converted '{key_string}' to keycode successfully")
                return keycode
            except AttributeError:
                print(f"Warning: Unknown key '{key_string}', using KC.NO")
                return KC.NO
        else:
            print(f"Warning: Invalid key format '{key_string}', using KC.NO")
            return KC.NO

    def update_keymap_from_bindings(self, keybindings, layer=0):
        """Update the keyboard's keymap with new key bindings"""
        print(f"Updating layer {layer} with {len(keybindings)} key bindings")
        
        new_keycodes = []
        for key_string in keybindings:
            keycode = self.string_to_keycode(key_string)
            new_keycodes.append(keycode)
        
        # Make sure we have enough layers
        while len(self.keyboard.keymap) <= layer:
            self.keyboard.keymap.append([KC.NO] * len(self.keyboard.keymap[0]))
        
        # Update the specific layer
        self.keyboard.keymap[layer] = new_keycodes
        print(f"Keymap layer {layer} updated with {len(new_keycodes)} keys")

    def process_serial_command(self):
        """Process serial commands without blocking"""
        if not supervisor.runtime.serial_bytes_available:
            return
            
        try:
            command_line = sys.stdin.readline()
            
            if not command_line:
                return
                
            command_line = command_line.strip()
            if not command_line:
                return

            print(f"[KMK] Received: {command_line}")

            # Parse JSON
            try:
                command = json.loads(command_line)
            except json.JSONDecodeError as e:
                print(f"[KMK] JSON Error: {str(e)}")
                error_response = {"status": "error", "message": f"Invalid JSON: {str(e)}"}
                print(json.dumps(error_response))
                return

            # Process commands
            action = command.get("action")
            print(f"[KMK] Processing action: {action}")

            if action == "ping":
                print("[KMK] Ping received, sending pong")
                response = {"status": "success", "message": "pong", "timestamp": time.monotonic()}
                print(json.dumps(response))

            elif action == "set_keybindings":
                keybindings = command.get("keybindings", [])
                layer = command.get("layer", 0)
                layer_name = command.get("layer_name")
                
                print(f"[KMK] Setting {len(keybindings)} keybindings on layer {layer}")

                if not keybindings:
                    response = {"status": "error", "message": "No keybindings provided"}
                else:
                    try:
                        self.update_keymap_from_bindings(keybindings, layer)
                        
                        response = {
                            "status": "success",
                            "message": f"Updated {len(keybindings)} keys on layer {layer}",
                            "keybindings_received": keybindings,
                        }
                        print(f"[KMK] Successfully updated keymap")
                    except Exception as e:
                        print(f"[KMK] Error updating keymap: {str(e)}")
                        response = {"status": "error", "message": f"Failed to update keymap: {str(e)}"}

                if len(keyboard.layer_names) <= layer:
                    keyboard.layer_names.extend([None] * (layer - len(keyboard.layer_names) + 1))

                keyboard.layer_names[layer] = layer_name

                print(json.dumps(response))

            elif action == "save_config":
                if hasattr(self.keyboard, 'config_module'):
                    success = self.keyboard.config_module.force_save()
                    if success:
                        response = {"status": "success", "message": "Configuration saved"}
                    else:
                        response = {"status": "error", "message": "Failed to save configuration"}
                else:
                    response = {"status": "error", "message": "Config module not available"}
                print(json.dumps(response))

            elif action == "load_config":
                if hasattr(self.keyboard, 'config_module'):
                    success = self.keyboard.config_module.load_config()
                    if success:
                        response = {"status": "success", "message": "Configuration loaded"}
                    else:
                        response = {"status": "error", "message": "Failed to load configuration"}
                else:
                    response = {"status": "error", "message": "Config module not available"}
                print(json.dumps(response))

            elif action == "get_config_info":
                if hasattr(self.keyboard, 'config_module'):
                    config_info = self.keyboard.config_module.get_config_info()
                    response = {"status": "success", "config_info": config_info}
                else:
                    response = {"status": "error", "message": "Config module not available"}
                print(json.dumps(response))

            elif action == "get_current_keymap":
                try:
                    print("[KMK] Getting current keymap")
                    keymap_strings = []
                    for layer_idx, layer in enumerate(self.keyboard.keymap):
                        layer_strings = []
                        for keycode in layer:
                            layer_strings.append(str(keycode))
                        keymap_strings.append(layer_strings)

                    response = {
                        "status": "success",
                        "keymap": keymap_strings,
                        "layers": len(self.keyboard.keymap)
                    }
                except Exception as e:
                    print(f"[KMK] Error getting keymap: {str(e)}")
                    response = {"status": "error", "message": f"Failed to get keymap: {str(e)}"}

                print(json.dumps(response))

            else:
                print(f"[KMK] Unknown action: {action}")
                response = {"status": "error", "message": f"Unknown action: {action}"}
                print(json.dumps(response))

        except Exception as e:
            print(f"[KMK] Command processing error: {str(e)}")
            error_response = {"status": "error", "message": f"Command processing error: {str(e)}"}
            print(json.dumps(error_response))

# Initialize hardware and modules
layer_names = ["temp"]
displayio.release_displays()
i2c = busio.I2C(scl=board.SCL, sda=board.SDA, frequency=400000)
Kpad_oled = True

keyboard = Kpad(i2c, layer_names, Kpad_oled)
layers = Layers()
holdtap = HoldTap()
macros = Macros()
encoder_handler = EncoderHandler()
encoder_handler.divisor = 4

# Add our custom serial module
serial_module = SerialCommandModule()

# Add all modules to keyboard
keyboard.modules = [layers, encoder_handler, holdtap, macros, serial_module]

encoder_handler.pins = ((board.D9, board.D10, board.D8,),)
keyboard.extensions.append(MediaKeys())

class InactivityDetector(Module):
    def __init__(self, timeout_seconds=10):
        self.timeout_seconds = timeout_seconds
        self.last_activity_time = time.monotonic()
        self.inactivity_triggered = False
    
    def during_bootup(self, keyboard):
        # Store reference to self in keyboard for easy access
        keyboard.inactivity_detector = self
    
    def before_matrix_scan(self, keyboard):
        current_time = time.monotonic()
        seconds_inactive = current_time - self.last_activity_time
        
        if seconds_inactive >= self.timeout_seconds and not self.inactivity_triggered:
            self.on_inactivity(keyboard)
            self.inactivity_triggered = True
    
    def after_matrix_scan(self, keyboard):
        pass
    
    def before_hid_send(self, keyboard):
        pass
    
    def after_hid_send(self, keyboard):
        pass
    
    def process_key(self, keyboard, key, is_pressed, int_coord):
        if is_pressed:
            self.reset_timer()
        return key
    
    def reset_timer(self):
        """Public method to reset the inactivity timer"""
        self.last_activity_time = time.monotonic()
        self.inactivity_triggered = False
    
    def on_inactivity(self, keyboard):
        print("No activity for {} seconds!".format(self.timeout_seconds))

        keyboard.oled.set_scene(0)
        

inactivity_detector = InactivityDetector(timeout_seconds=10)
keyboard.modules.append(inactivity_detector)


class OLEDLayerKey():
    def __init__(self, *args, **kwargs):
        super().__init__()
        
    def on_press(self, keyboard, *args, **kwargs):

        if hasattr(keyboard, 'inactivity_detector'):
            keyboard.inactivity_detector.reset_timer()

        # Save current scene and show a specific OLED scene
        if hasattr(keyboard, 'oled'):
            keyboard.oled.set_scene(1)  # sets the scene to end of the two scenes (Selection Scene)
        # Change layer
        if DisplayScene._current_layer != keyboard.active_layers[0]:
            KC.DF(DisplayScene._current_layer).on_press(keyboard, *args, **kwargs) 
        return False
        
    def on_release(self, keyboard, *args, **kwargs):
        active_scene = keyboard.oled._get_active_scene()
        if active_scene:
            active_scene.forced_draw(keyboard.oled, keyboard)
        
        return False


class selection_NXT_layer():
    def __init__(self, *args, **kwargs):
        super().__init__(*args, **kwargs)

    def on_press(self, keyboard, *args, **kwargs):

        if hasattr(keyboard, 'inactivity_detector'):
            keyboard.inactivity_detector.reset_timer()

        # Save current scene and show a specific OLED scene
        if hasattr(keyboard, 'oled'):
            keyboard.oled.set_scene(1)  # sets the scene to end of the three scenes (Selection Scene)
        # Change layer
        
        if DisplayScene._current_layer < len(keyboard.keymap) - 1:
            DisplayScene._current_layer += 1
        else:
            DisplayScene._current_layer = 0
        return False
        
    def on_release(self, keyboard, *args, **kwargs):
        return False

class selection_PRV_layer():
    def __init__(self, *args, **kwargs):
        super().__init__(*args, **kwargs)

    def on_press(self, keyboard, *args, **kwargs):

        if hasattr(keyboard, 'inactivity_detector'):
            keyboard.inactivity_detector.reset_timer()

        # Save current scene and show a specific OLED scene
        if hasattr(keyboard, 'oled'):
            keyboard.oled.set_scene(2)  # sets the scene to end of the three scenes (Selection Scene)
        # Change layer
        if DisplayScene._current_layer == 0:
            DisplayScene._current_layer = len(keyboard.keymap) - 1
        else:
            DisplayScene._current_layer -= 1
        return False
        
    def on_release(self, keyboard, *args, **kwargs):
        return False


SELECT = OLEDLayerKey()
SEL_NXT = selection_NXT_layer()
SEL_PRV = selection_PRV_layer()


# === DEFAULT KEYMAP ===
keyboard.keymap = [
    [
        KC.A,    KC.B,    KC.C,     # Row 1
        KC.D,    KC.E,    KC.F,     # Row 2
        KC.G,    KC.H,    KC.I,     # Row 3
        KC.J,    KC.K,    KC.L,     # Row 4
    ]
]

encoder_handler.map = [ 
    ((SEL_PRV, SEL_NXT, SELECT),), # NumPad
    ((SEL_PRV, SEL_NXT, SELECT),), # Function
]

# Let KMK handle the main loop - serial processing happens in before_matrix_scan
if __name__ == '__main__':
    
    keyboard.go()
    

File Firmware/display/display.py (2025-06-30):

"""
This file is adapted from Tonasz's display.py in https://github.com/Tonasz/kmk_firmware/blob/display/kmk/extensions/display.py 

Thanks to Tonasz for their contribution.
"""
from supervisor import ticks_ms

import adafruit_displayio_ssd1306
import displayio
import i2cdisplaybus
import terminalio   
from adafruit_display_text import label

from kmk.extensions import Extension
from kmk.handlers.stock import passthrough as handler_passthrough
from kmk.keys import make_key


class Display(Extension):
    I2C_ADDRESS = 0x3C

    def __init__(
        self, i2c, scenes, *, width=128, height=64, rotation=0, address=I2C_ADDRESS
    ):

        display_bus = i2cdisplaybus.I2CDisplayBus(i2c, device_address=address)
        self.width = width
        self.height = height
        self._display = adafruit_displayio_ssd1306.SSD1306(
            display_bus, width=width, height=height, rotation=rotation
        )
        self._scenes = scenes
        self._current_scene = 0
        self._saved_scene = 0
        self._redraw_forced = False
        self._asleep = False
        self.polling_interval = 100
        self._last_tick = ticks_ms()

        make_key(
            names=('OLED_NXT',),
            on_press=self._tb_next_scene,
            on_release=handler_passthrough,
        )

        make_key(
            names=('OLED_PRV',),
            on_press=self._tb_prev_scene,
            on_release=handler_passthrough,
        )

        make_key(
            names=('OLED_TOG',),
            on_press=self._tb_toggle,
            on_release=handler_passthrough,
        )

    def during_bootup(self, keyboard):
        self._redraw_forced = True
        for scene in self._scenes:
            scene.initialize(self, keyboard)
        self._display.root_group = self._get_active_scene().scene_group

    def before_matrix_scan(self, keyboard):
        pass

    def after_matrix_scan(self, keyboard):
        pass

    def before_hid_send(self, keyboard):
        pass

    def after_hid_send(self, keyboard):
        if self._asleep:
            return

        scene = self._get_active_scene()
        now = ticks_ms()
        ready = (
            now - self._last_tick >= scene.polling_interval
        ) and scene.is_redraw_needed(keyboard)
        if self._redraw_forced or ready:
            if self._redraw_forced:
                scene.forced_draw(self, keyboard)
            else:
                scene.draw(self, keyboard)
            self._redraw_forced = False
            self._last_tick = now
        return

    def on_runtime_enable(self, keyboard):
        pass

    def on_runtime_disable(self, keyboard):
        pass

    def on_powersave_enable(self, keyboard):
        pass

    def on_powersave_disable(self, keyboard):
        pass

    def _get_active_scene(self):
        if len(self._scenes) > self._current_scene:
            return self._scenes[self._current_scene]

    def _tb_next_scene(self, *args, **kwargs):
        self._current_scene += 1
        if self._current_scene >= len(self._scenes):
            self._current_scene = 0
        self._redraw_forced = True
        self._display.root_group = self._get_active_scene().scene_group

    def _tb_prev_scene(self, *args, **kwargs):
        self._current_scene -= 1
        if self._current_scene < 0:
            self._current_scene = len(self._scenes) - 1
        self._redraw_forced = True
        self._display.root_group = self._get_active_scene().scene_group

    def _tb_toggle(self, *args, **kwargs):
        if self._asleep:
            self._asleep = False
            self._redraw_forced = True
            self._display.wake()
        else:
            self._asleep = True
            self._display.sleep()

    def set_scene(self, scene_num):
        """
        Set the current scene to a specific index number.
        
        Args:
            scene_num: The index of the scene to display.
                       If out of range, it will be clamped to valid values.
        """
        # Ensure scene_num is within valid range
        if scene_num < 0:
            scene_num = 0
        elif scene_num >= len(self._scenes):
            scene_num = len(self._scenes) - 1
            
        # Only change if needed
        if self._current_scene != scene_num:
            self._current_scene = scene_num
            self._redraw_forced = True
            self._display.root_group = self._get_active_scene().scene_group
            
        return self._current_scene  # Return the actual scene number used
    
    # Convenience method to make a key for setting a specific scene
    def make_scene_key(self, scene_num):
        """
        Create a key that will switch directly to the specified scene.
        
        Args:
            scene_num: The scene index to switch to when this key is pressed
            
        Returns:
            A key object that can be used in a keymap
        """
        return make_key(
            names=(f'OLED_SCN{scene_num}',),
            on_press=lambda *args, **kwargs: self.set_scene(scene_num),
            on_release=handler_passthrough,
        )

class DisplayScene:
    '''Abstract class, which all other scenes depends on'''

    _display_layer = 0
    _current_layer = 0
    polling_interval = 40

    def is_redraw_needed(self, sandbox):
        '''Obligatory check, if we can skip draw logic.
        It was more important when module was based on framebuf.'''
        raise NotImplementedError

    def initialize(self, oled, sandbox):
        '''Called once during_bootup'''
        self.scene_group = None

    def forced_draw(self, oled, sandbox):
        '''Method called when draw is forced, ie when scene is changed.
        It was more important when module was based on framebuf, now maybe obsolete.'''
        self.draw(oled, sandbox)

    def draw(self, oled, sandbox):
        '''Obligatory function, defines main scene logic. Happens not more often than polling_interval.'''
        raise NotImplementedError


class BitmapLogoScene(DisplayScene):
    '''Displays bitmap from storage'''

    def __init__(self, path):
        self._path = path

    def is_redraw_needed(self, sandbox):
        return False

    def initialize(self, oled, sandbox):
        self.scene_group = displayio.Group()

        bitmap = displayio.OnDiskBitmap(self._path)
        tile_grid = displayio.TileGrid(bitmap, pixel_shader=bitmap.pixel_shader)
        self.scene_group.append(tile_grid)

    def draw(self, oled, sandbox):
        pass


from kmk.extensions.rgb import AnimationModes
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
